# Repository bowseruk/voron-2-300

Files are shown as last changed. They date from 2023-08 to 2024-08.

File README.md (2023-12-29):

# Voron 2.4 300mm

)

## Description

This Repo is for keeping all the details of my Voron 2.4r2 300 mm.

The project had the following aims:

- It has a place to store all STLs used to make the printer.

- Relevant documentation used in the build is stored.

- Store the relevant configuration files that have been modified and used in this build.

- Add some scripts to help maintain the printer.

## Table of Contents

- [Description](#description)

- [Table of Contents](#table-of-contents)

- [Installation](#installation)

- [Usage](#usage)

- [Features](#features)

- [Parts](#parts)

- [Credits](#credits)

- [License](#license)

## Installation

The project does not require installation steps.

## Usage

This is a record of everything in use on my printer. Feel free to use anything on this Repo when building your printer.

## Features

This project has the following features:

- Script to update canbus firmware.

- Saved configuration files based on research and experimentation to date.

## Parts

The printer was built with:

- A Formbot 2.4r2 kit with Dragon HF, Octopus Pro and Raspberry Pi 3.

It has been modified with the following upgrades:

- 2020 extrusion covers to neaten led, camera and thermistor wiring.

- ACM Deck and Back Panels

- BTT Smart Sensor v2

- BTT Relay v1.2 and mount

- BTT UPS 24v and mount

- Chaotic Labs CNC Kit (Part of it) (Z and X/Y Idlers and A/B motor mount)

- Corner Cable Cover

- Daylight on a Stick (x2) and mount

- Disco on a Stick and mount

- Extrusion Backers

- Fysetc PITB

- G5EC Z Joints

- IGUS Z chain (Formbot supplied one was too thick and interfered with the y endstop)

- Kinematic Bed + Bed Wagos

- LDO rails on Y (after a rail lost it bearings)

- Logitech C930C and mount

- Mellow Fly-SB2040

- Nevermore Micro V5

- Pi Camera and mount

- POWGE Z Gears (Formbot supplied one had a strip grub on gear, so damaged it getting it off)

- Raspberry Pi Mount

- Stealthburner

- Thermistors and mounts on gantry and top of enclosure

- WAGO mounts

- Wiring (large amount replaced or customised)

- Z Belt clips

## Credits

The following resources were important for this project.

- [Readme Generator](https://github.com/bowseruk/readme-generator-nodejs) for generating the readme.

- [Voron Design](https://vorondesign.com/voron2.4) for creating a great printer.

- [Klipper](https://www.klipper3d.org/) documentation has helped me a lot.

- [Katapult]()

- [Fluidd]()

- [Formbot](https://www.formbot3d.com/collections/voron-24)

- [2020 extrusion clips]()

- [BTT Octopus Pro](https://github.com/bigtreetech/BIGTREETECH-OCTOPUS-Pro) documentation for the Octopus Pro Board.

- [BTT Smart Filament Mount](https://mods.vorondesign.com/detail/yrBU4iTiddQRSvLqSDWMuA) by Empusas

- [BTT Relay v1.2 mount]()

- [BTT UPS 24v Mount](https://mods.vorondesign.com/detail/fyvvcExQHVCdg67SgMWcQ) by Oakman

- [Chaotic Labs CNC Kit](https://chaoticlab.xyz/) (Part of it) (Z and X/Y Idlers and A/B motor mount)

- [Corner Cable Cover](https://mods.vorondesign.com/detail/rXJYi9H1vNzno2fZlwAB3g)

- [Daylight on a Stick](https://github.com/VoronDesign/Voron-Hardware/tree/master/Daylight) and [mount]()

- [Disco on a Stick](https://github.com/VoronDesign/Voron-Hardware/tree/master/Daylight/Disco_on_a_stick) and [mount]()

- [Extrusion Backers](https://mods.vorondesign.com/detail/ewDI1Cntz7urtuq3Cm9wGQ)

- [Fysetc PITB](https://github.com/FYSETC/FYSETC-PITB)

- [G5EC Z Joints](https://mods.vorondesign.com/detail/eB5T2RNQcYI4o6cilhpXEg) by hartk1213.

- [Kinematic Bed + Bed Wagos](https://github.com/tanaes/whopping_Voron_mods/tree/main/kinematic_bed)

- [Logitech C930C mount](https://mods.vorondesign.com/detail/HScp6sF2ld2ncp8XV99RDA)

- [Mellow SB2040](https://mellow-3d.github.io/fly_sb2040_v1_general.html) documentation for the Mellow Fly-SB2040.

- [Nevermore](https://github.com/nevermore3d/Nevermore_Micro)

- [Pi Camera mount](https://github.com/VoronDesign/VoronUsers/tree/master/printer_mods/richardjm/picam-corner)

- [Raspberry Pi Mount](https://mods.vorondesign.com/detail/cd8PlaXqhTQsgKSmgcPHw)

- [Stealthburner](https://vorondesign.com/voron_stealthburner)

- [Thermistor mounts on gantry](https://mods.vorondesign.com/detail/x6rfcH51foFjGStyvPXnw)

- [Thermistor mounts on top of enclosure](https://mods.vorondesign.com/detail/dfRX88k7wwS6tpYlvyCEw)

- [WAGO mounts](https://mods.vorondesign.com/detail/u6PTkFoOllSE4jmasKCHQ)

- [Z Belt clips](https://mods.vorondesign.com/detail/UrXS8J4mIe1K3XGGagS5Q)

## License

)

This project is licensed under the [GNU GPL v3](https://opensource.org/license/gpl-3-0/) license.

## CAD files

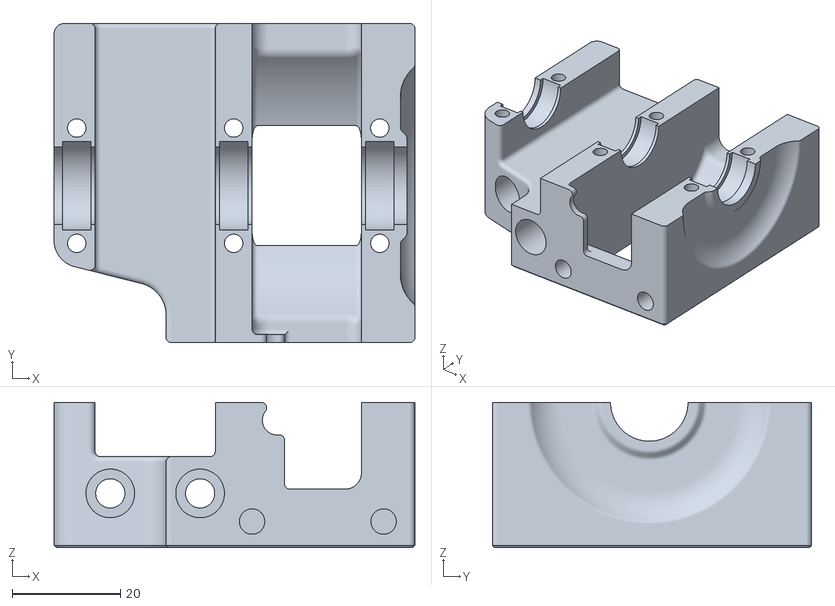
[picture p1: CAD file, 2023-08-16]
stl/Z Drive/z_drive_main_b_x2.stl
66.7 x 59.0 x 26.8

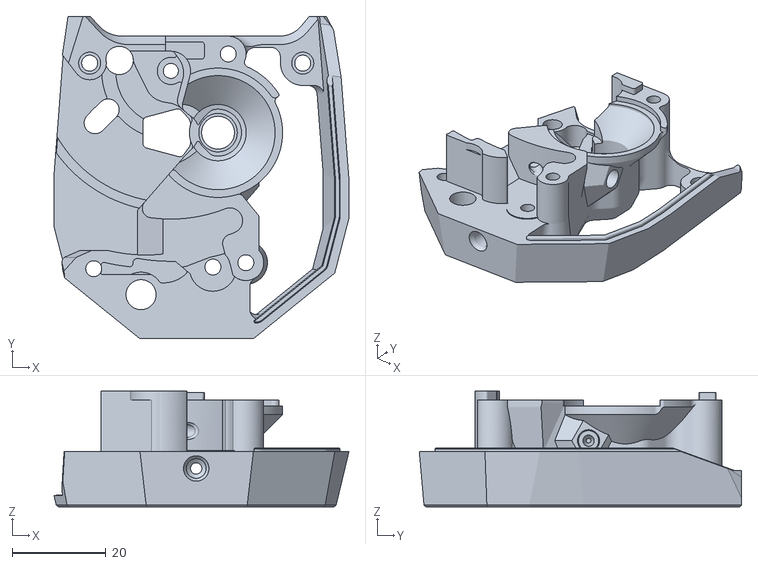
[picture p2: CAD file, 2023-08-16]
stl/Tools/main_body.stl
62.8 x 68.7 x 24.7

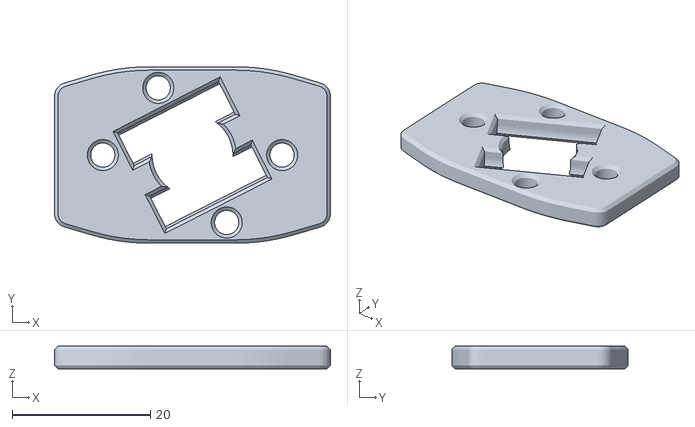
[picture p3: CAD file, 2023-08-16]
stl/Bed/[a]_sandwich_spacers-front_right.stl
40.0 x 25.5 x 3.30

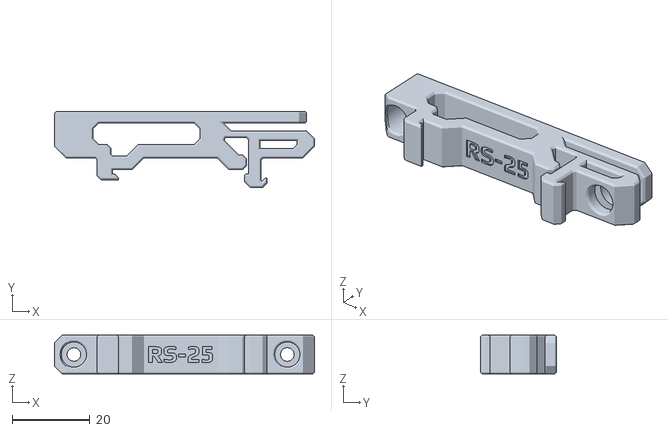
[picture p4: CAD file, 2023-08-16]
stl/Electronics Bay/rs25_psu_bracket.stl
67.0 x 19.6 x 10.0

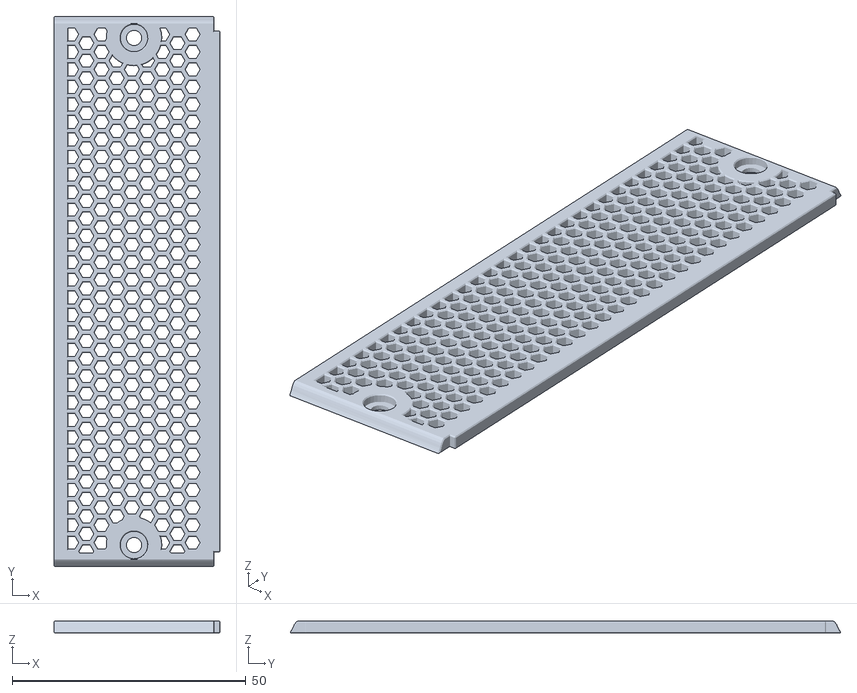
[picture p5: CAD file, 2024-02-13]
stl/Exhaust FIlter/1_lid.stl
35.5 x 117.8 x 2.55

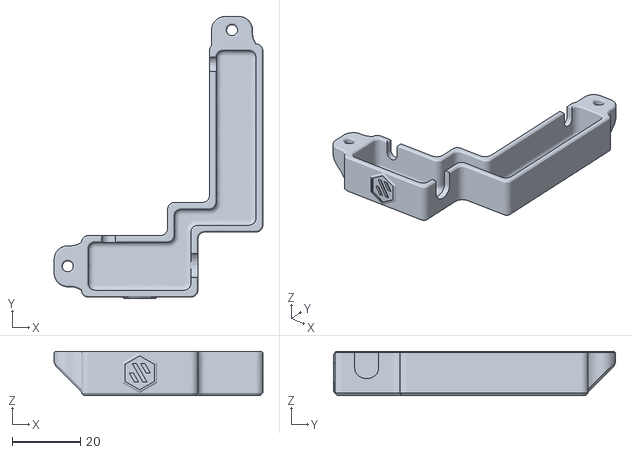
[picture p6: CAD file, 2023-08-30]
stl/Frame/[a]_top_corner_right_hide.stl
61.0 x 82.4 x 13.0

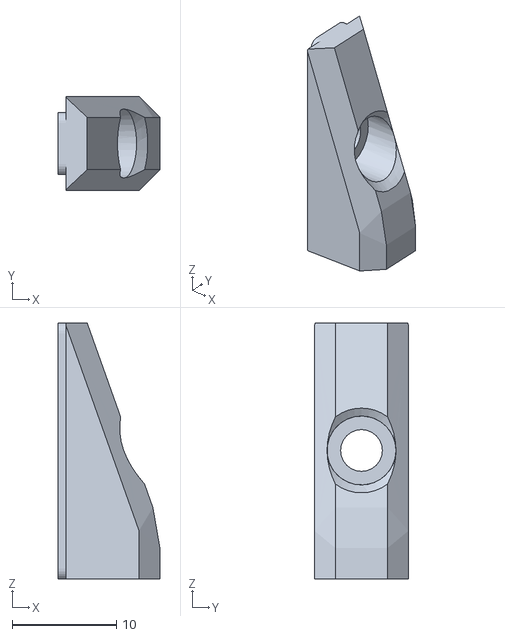
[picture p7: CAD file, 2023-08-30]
stl/Gantry/2020 Rail Endstop.stl
9.75 x 9.00 x 24.5

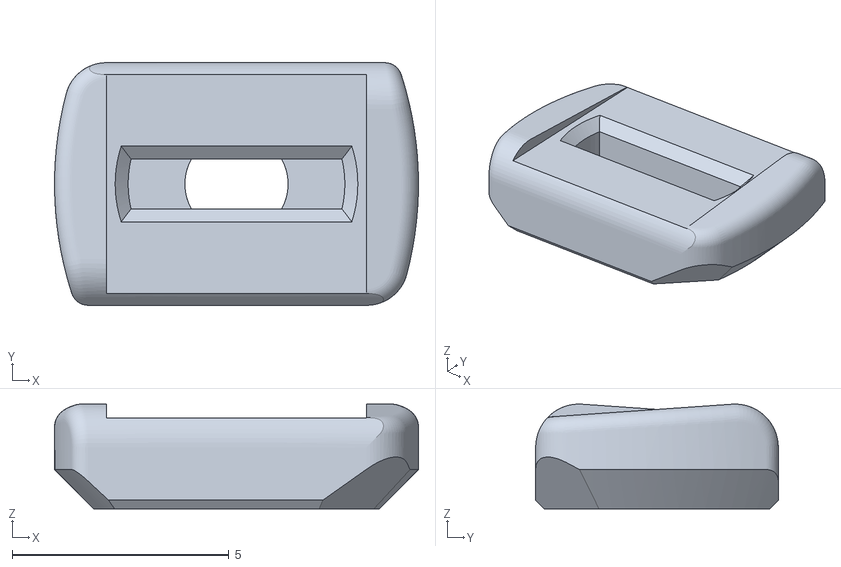
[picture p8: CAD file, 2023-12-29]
stl/Panel Mount/Unhammer-v2-Flat-Head.stl
8.40 x 5.60 x 2.42

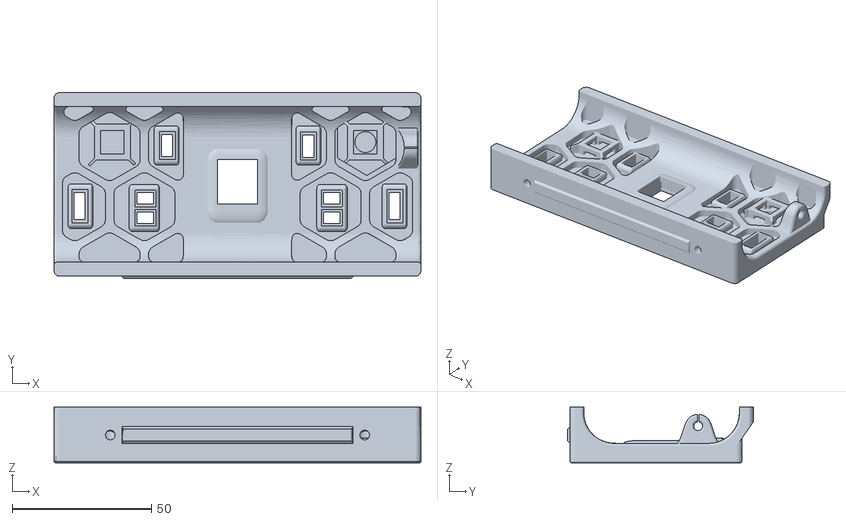
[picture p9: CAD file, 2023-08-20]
stl/Skirts/rear_center_skirt_300_custom.stl
132.0 x 66.8 x 20.0

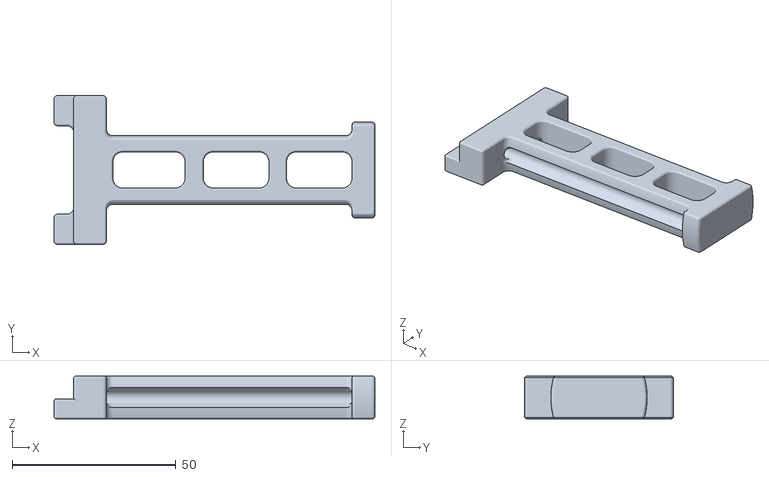
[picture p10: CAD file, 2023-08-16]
stl/Spool Management/spool_holder.stl
98.0 x 45.4 x 13.0

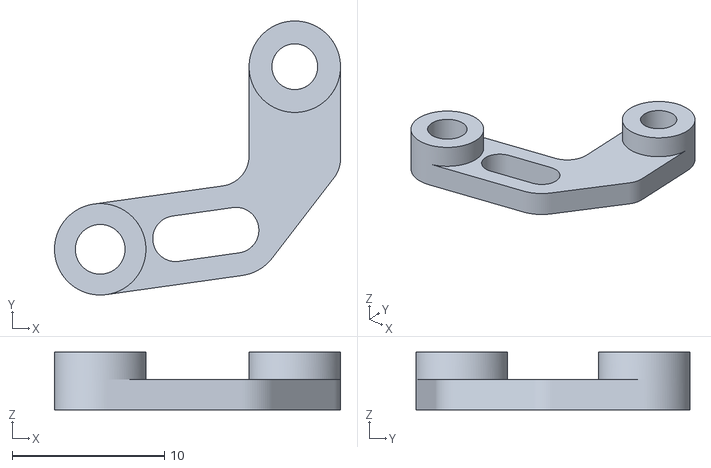
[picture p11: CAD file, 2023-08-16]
stl/Stealthburner/[a]_pcb_spacer.stl
18.8 x 18.0 x 3.80

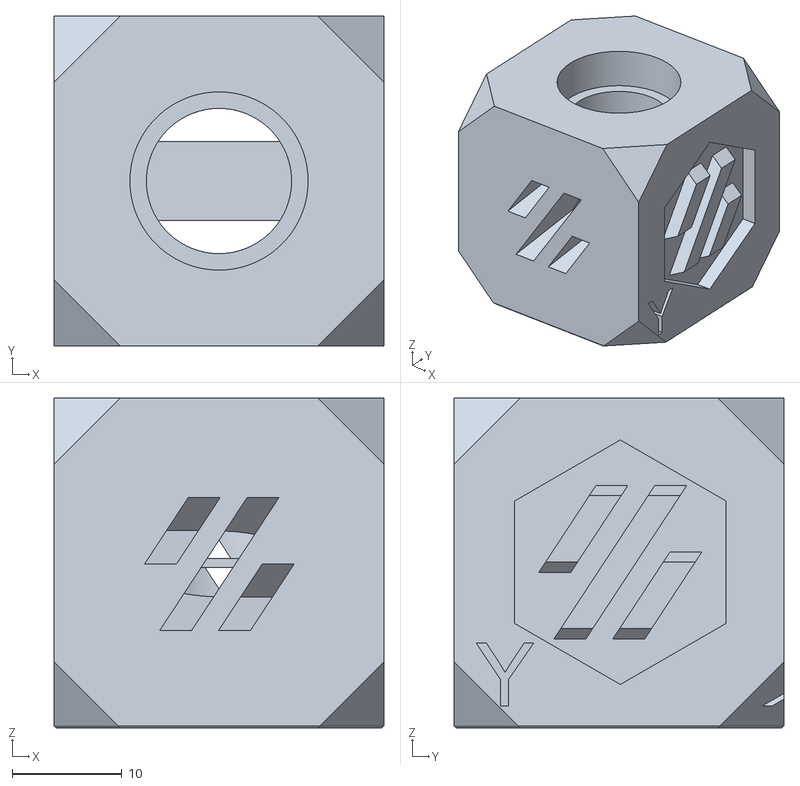
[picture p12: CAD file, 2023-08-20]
stl/Tools/Voron_Design_Cube_v7.stl
30.0 x 30.0 x 30.0

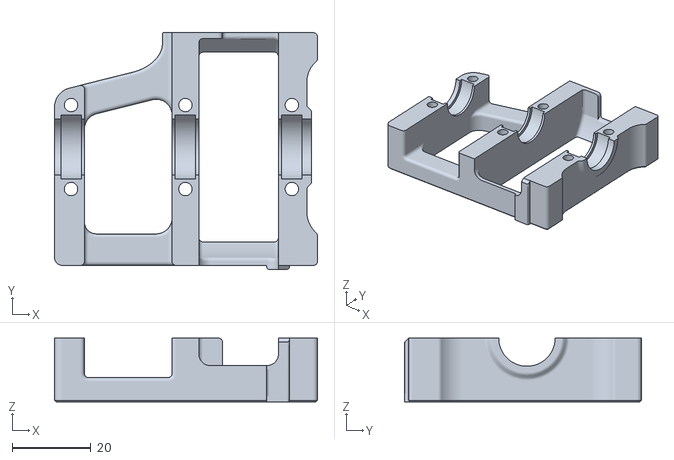
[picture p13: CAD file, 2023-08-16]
stl/Z Drive/z_drive_retainer_b_x2.stl
66.7 x 60.0 x 16.2

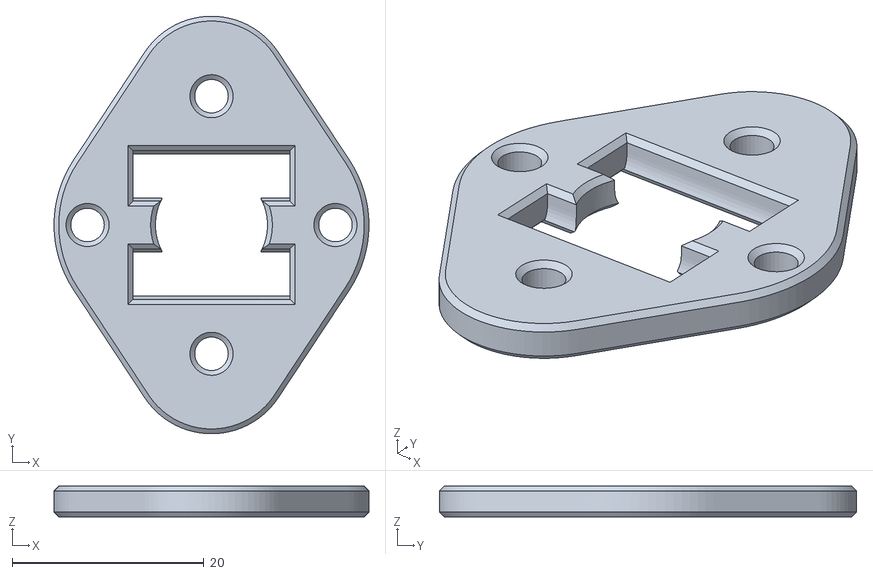
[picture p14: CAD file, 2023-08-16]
stl/Bed/[a]_sandwich_spacers-back_center.stl
32.9 x 43.6 x 3.20

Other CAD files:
stl/Z Drive/z_drive_main_a_x2.stl
stl/Electronics Bay/Wago_3x_221-415_DIN_Mount.stl
stl/Exhaust FIlter/exhaust_filter_housing(r2)Filament-Sensor.stl
stl/Frame/[a]_top_corner_left_hide.stl
stl/Bed/Bed_Support_Alignment_Tool_300_Corners_x4.stl
stl/Bed/Bed_Support_Alignment_Tool_Center_250_300_350_x2.stl
stl/Bed/Bed_WAGO.stl
stl/Bed/V2_Duo_Plenum.stl
stl/Bed/V2_Duo_Plenum_LID.stl
stl/Bed/[a]_sandwich_spacers-front_left.stl
stl/Electronics Bay/BTT_UPS_24V_DIN.stl
stl/Electronics Bay/Din_Mount_Bracket.stl
stl/Electronics Bay/Octopus_bracket_set.stl
stl/Electronics Bay/PSU_stabilizer_50mm.stl
stl/Electronics Bay/RPI_Metal_DIN_Mount.stl
stl/Electronics Bay/Wago_3x_221-415_Skirt_Inlet_Mount.stl
stl/Electronics Bay/lrs_200_psu_bracket_x2.stl
stl/Electronics Bay/pcb_din_clip_x3.stl
stl/Electronics Bay/wago_221-415_mount_3by5.stl
stl/Exhaust FIlter/1_coal_with_mesh.stl
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

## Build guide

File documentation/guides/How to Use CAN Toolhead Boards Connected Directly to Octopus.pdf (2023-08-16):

How to Use CAN Toolhead Boards Connected Directly to Octopus / Octopus Pro on CanBoot

- Klipper has a new CAN bus feature, the USB to CAN bus bridge communication for Octopus boards (and other compatible MCUs).
- This feature allows the Octopus boards (and other compatible MCUs) to act as a USB to CAN bus adapter. This replaces the need for an adapter like a Raspberry Pi CAN HAT, canable adapter, or the Bigtreetech U2C board.

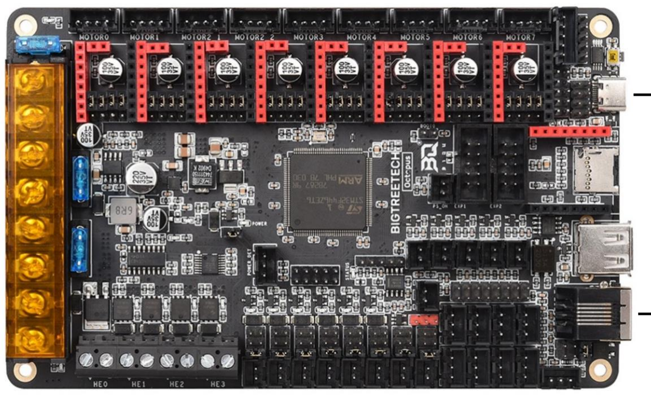
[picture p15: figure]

What is CanBoot?

- CanBoot is a custom bootloader loaded onto your Octopus and EBB board that allows users to update Klipper firmware over USB, UART, or CAN comms without physically having to access the board reset buttons or BOOT jumpers.
- It uses the same ‘make menuconfig’ setup to configure and compile firmware.
- CanBoot is NOT required to use the Klipper USB to CAN bus bridge comms. But I have not tested this comms feature separately.

You Will Need the Following

- USB-A to USB-C cable
- Power supply for Octopus and EBB toolboard (i.e. printer)
- RJ11 or RJ12 telephone cable, crimped to connect EBB board to Octopus
- See wiring info at end of guide. Best to setup wiring before installing software.
- Raspberry Pi, or similar, with Klipper / Moonraker / UI installed and working
- Computer with following software:
- SSH terminal software, I use PuTTY or Windows CMD
- WinSCP, to transfer files between Raspberry Pi and computer
- I also use Windows CMD to do this
- STM32CubeProgrammer
- Download for your computer OS and install
- https://www.st.com/en/development-tools/stm32cubeprog.html#get-software (https://www.st.com/en/development-tools/stm32cubeprog.html%23get-software)

High Level Instructions, for Understanding

1. Install CanBoot on Raspberry Pi, flash firmware to boards
a. Configure and compile CanBoot firmware for Octopus / Pro and EBB
b. Flash CanBoot to boards using STM32CubeProgrammer and computer
2. Setup boards for Klipper
a. Octopus - Setup Klipper for USB to CAN bus bridge, with CAN comms to EBB
b. EBB - Setup Klipper for CAN comms
c. Find serial device for Octopus / Pro on Raspberry Pi
d. Flash Klipper to Octopus / Pro with CanBoot serial command
3. Setup can0 network on Raspberry Pi, power cycle printer
4. Find CAN uuid for Boards
a. Connect EBB to Octopus / Pro, power cycle printer
5. Flash Klipper to EBB board with CanBoot CAN command
6. Printer Config Update and General Tips
7. How to Use CanBoot to update boards, Tips

Okay, enough talking! Let’s get started!

Instructions________________________________________________________________________

1. Install CanBoot on Raspberry Pi, flash firmware to boards

Start your SSH terminal.

sudo apt-get install git -y #Do this if you haven’t installed git yet…

git clone https://github.com/Arksine/CanBoot

cd CanBoot

make menuconfig

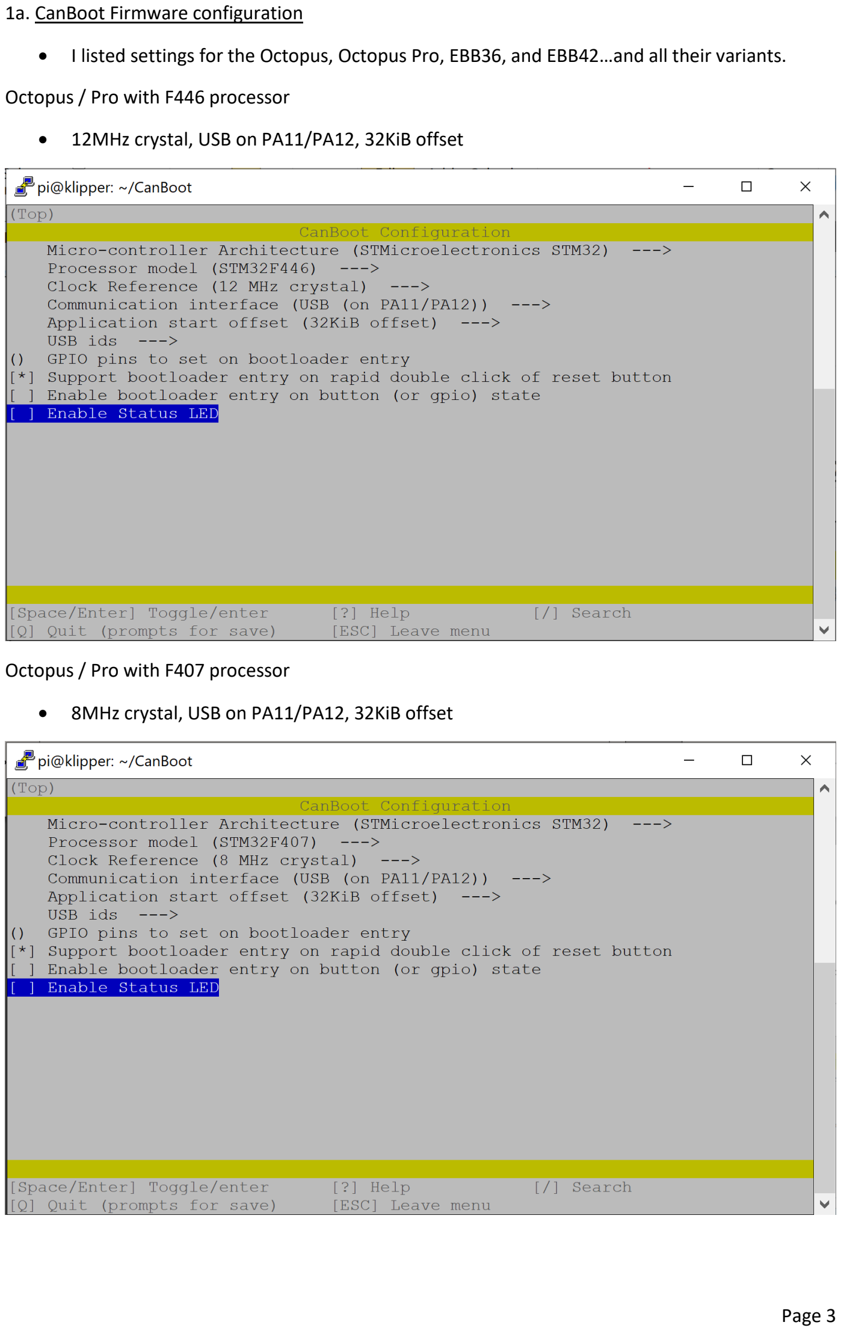
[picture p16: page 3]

1a. CanBoot Firmware configuration

- I listed settings for the Octopus, Octopus Pro, EBB36, and EBB42…and all their variants.

Octopus / Pro with F446 processor

- 12MHz crystal, USB on PA11/PA12, 32KiB offset

Octopus / Pro with F407 processor

- 8MHz crystal, USB on PA11/PA12, 32KiB offset

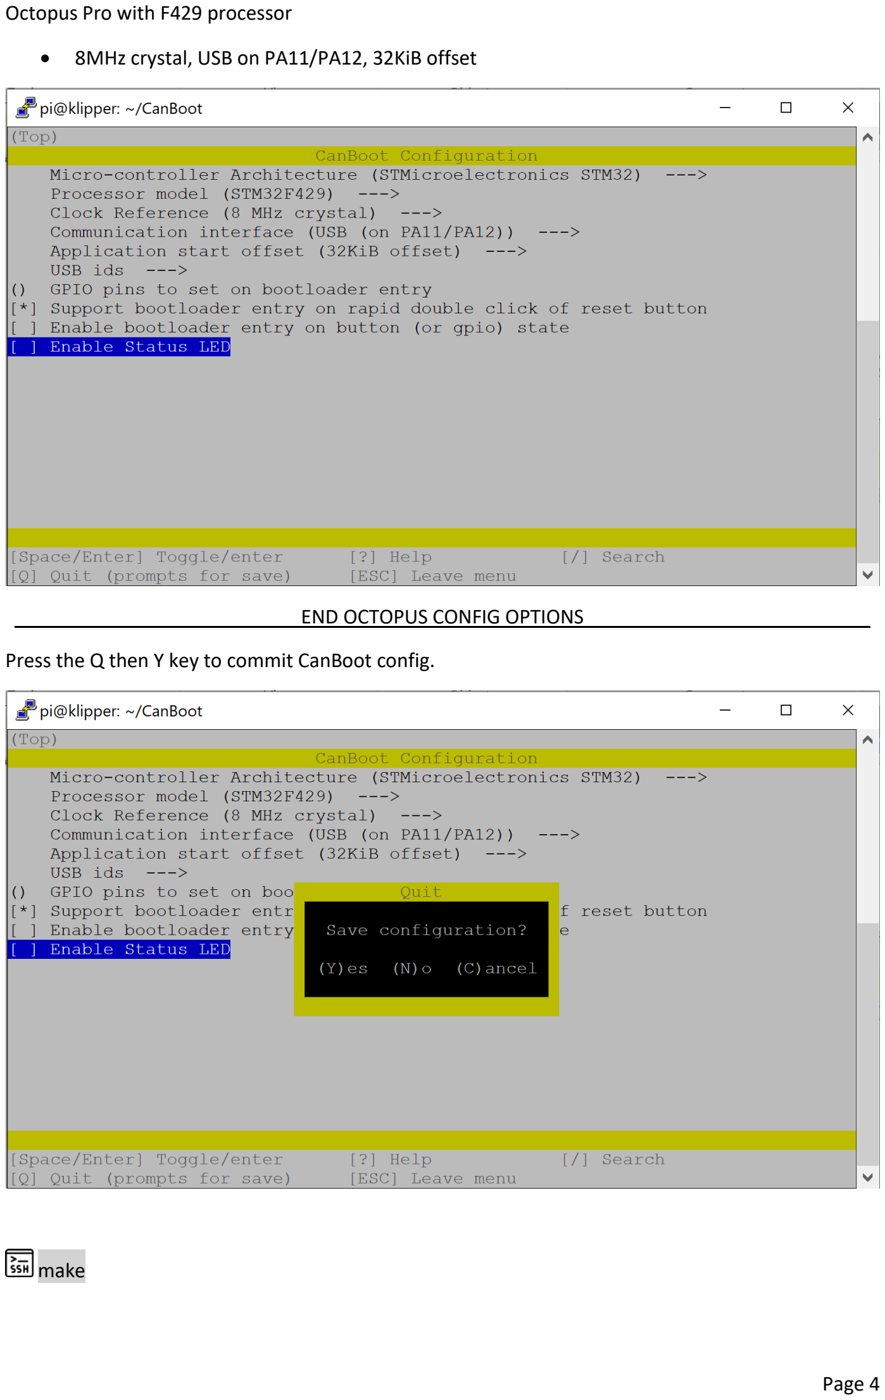
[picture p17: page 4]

Octopus Pro with F429 processor

- 8MHz crystal, USB on PA11/PA12, 32KiB offset

___________________________END OCTOPUS CONFIG OPTIONS___________________________

Press the Q then Y key to commit CanBoot config.

make

You have now created a canboot.bin firmware file for your Octopus board. My approach is to now make the CanBoot firmware for the EBB board. But if you do this now it will override the Octopus firmware you just created. So do the following:

On your computer, open a Windows CMD terminal

Type: pscp -C pi@<IP_ADDRESS>:/home/pi/CanBoot/out/canboot.bin octopus_canboot.bin

- Make sure to replace <IP_ADDRESS> with your Pi IP address or network name, like fluiddpi.local

NOTE: You can also manually move the canboot.bin file to your computer with WinSCP. Make sure to name it octopus_canboot.bin (or similar). We will be moving an ebb_canboot.bin file next.

…Back to the Raspberry Pi SSH terminal

make clean

make menuconfig

EBB36 / EBB42 v1.0 with F072 processor

- 8MHz crystal, CAN bus on PB8/PB9, 8KiB offset, 500000 CAN bus speed

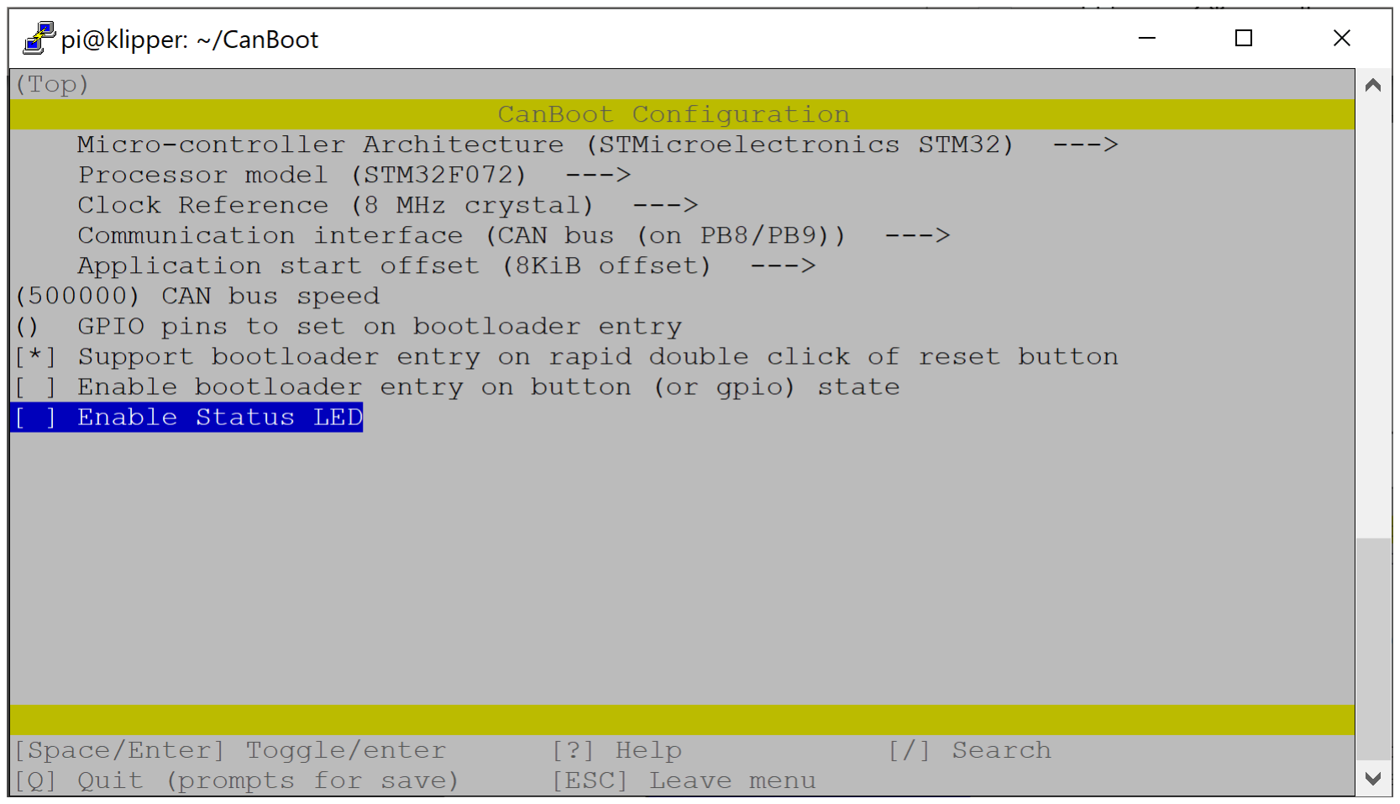
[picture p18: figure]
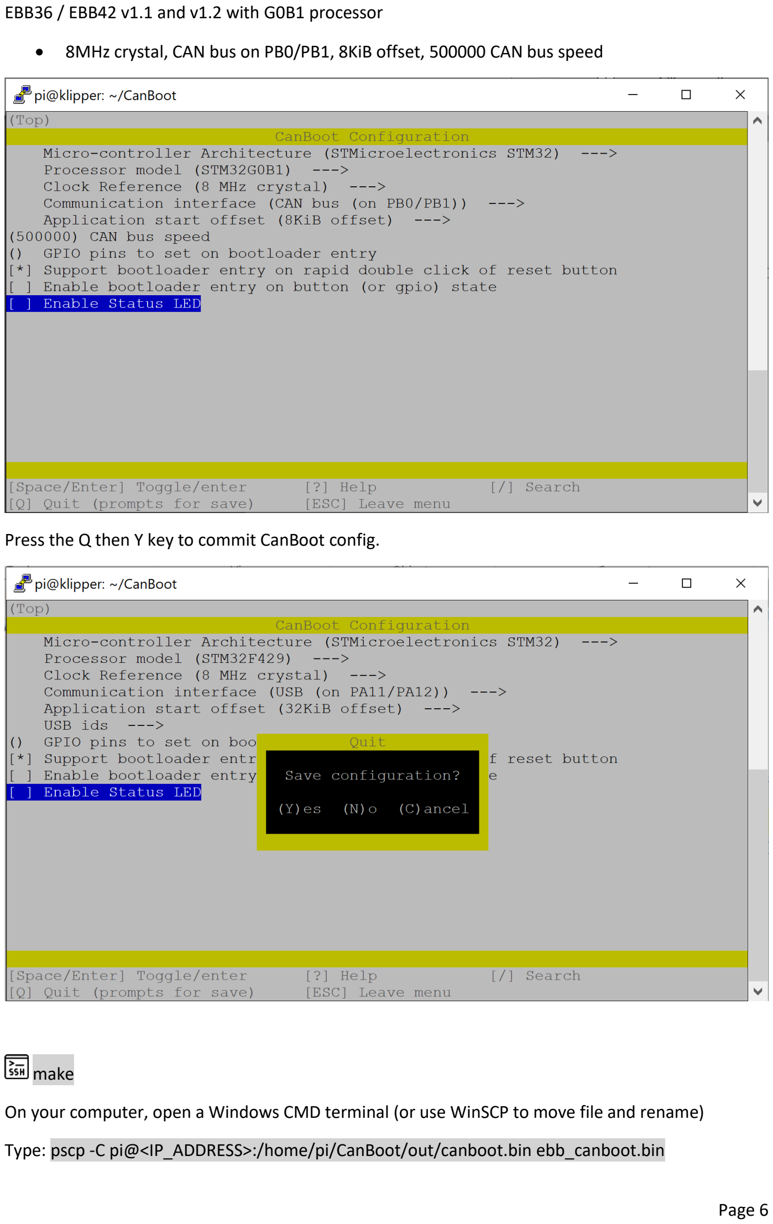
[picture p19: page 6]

EBB36 / EBB42 v1.1 and v1.2 with G0B1 processor

- 8MHz crystal, CAN bus on PB0/PB1, 8KiB offset, 500000 CAN bus speed

Press the Q then Y key to commit CanBoot config.

make

On your computer, open a Windows CMD terminal (or use WinSCP to move file and rename)

Type: pscp -C pi@<IP_ADDRESS>:/home/pi/CanBoot/out/canboot.bin ebb_canboot.bin

- Make sure to replace <IP_ADDRESS> with your Pi IP address or network name, like fluiddpi.local

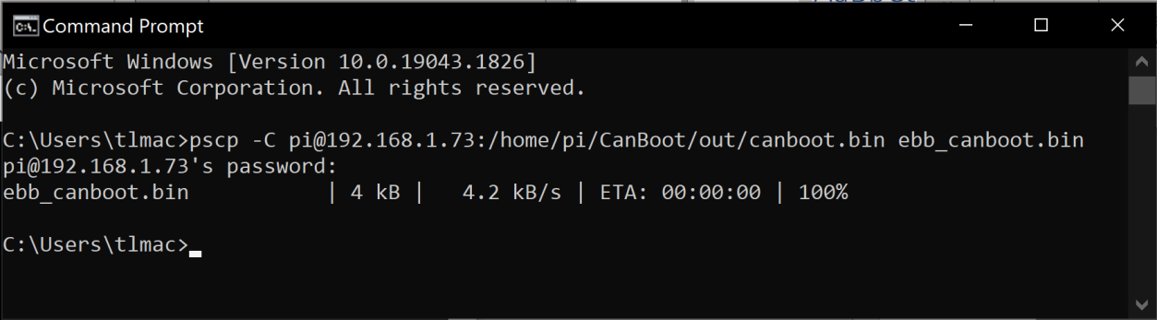
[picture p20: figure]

Your two CanBoot firmware files are now on your computer (in your user folder). Next step is to flash CanBoot to your boards.

1b. Flash CanBoot using STM32CubeProgrammer

You’ll need to put your boards into DFU mode and connect to the computer using a USB-A to USB-C cable. Boot instructions for the Octopus and Octopus Pro are below:

Make sure the power is off to the Octopus board

- To start have the USB-C to USB-A cable connected between the Windows PC and the Octopus Board.
- Remove the USB-C power jumper and place a jumper on the Boot0 header.

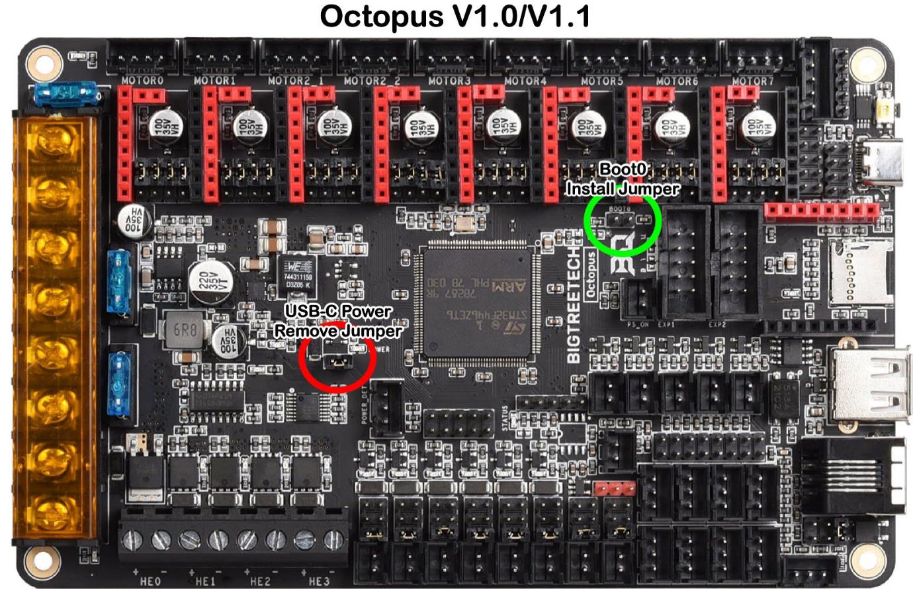
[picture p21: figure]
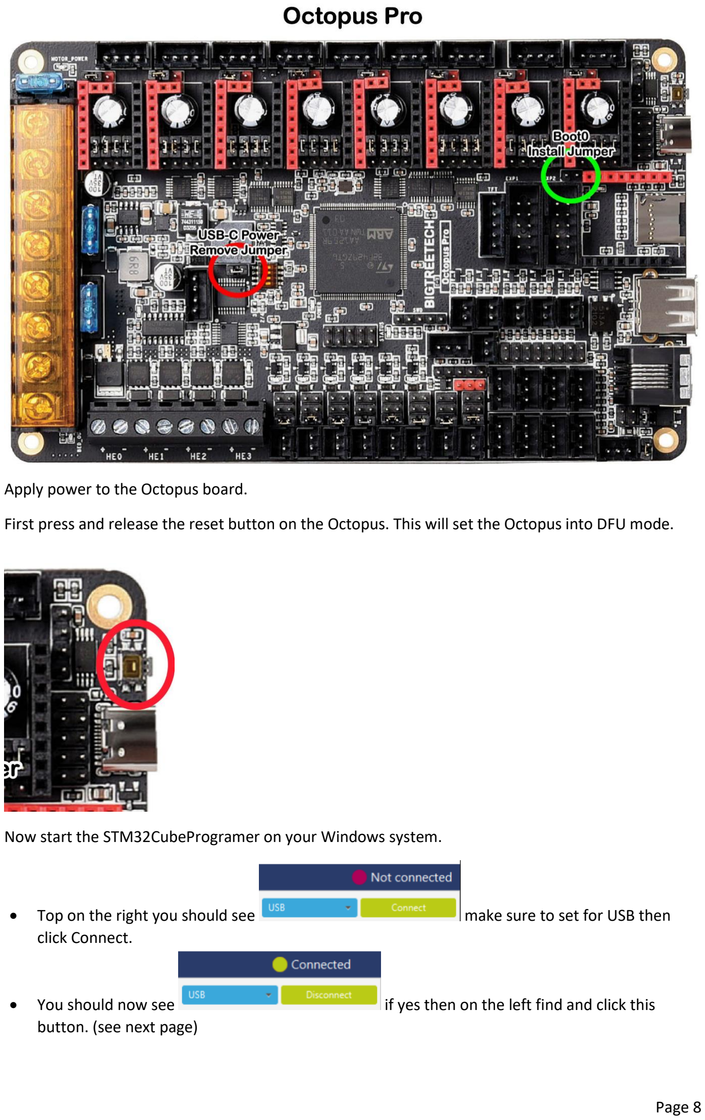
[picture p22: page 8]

Apply power to the Octopus board.

First press and release the reset button on the Octopus. This will set the Octopus into DFU mode.

Now start the STM32CubeProgramer on your Windows system.

- | Top on the right you should see | make sure to set for USB then
| click Connect.
- | You should now see | if yes then on the left find and click this
| button. (see next page)

- For CanBoot and Klipper to work correctly we need to wipe the flash memory by clicking this button.

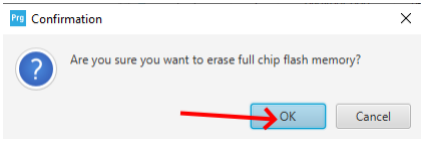
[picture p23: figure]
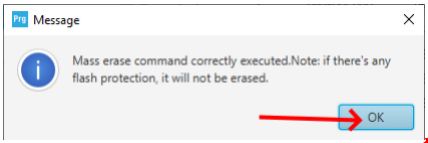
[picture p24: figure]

- Go back to main page by clicking on this button

- Select (1) “Open File” tab, find the octopus_canboot.bin file, and (2) download to your Octopus board. (3) Click Disconnect when done.

Power off your Octopus board. Remove the jumper from BOOT0.

Now you’ll flash your EBB toolboard.

This step will power the toolboard from USB only. Place a jumper on VBUS header.

EBB36 / EBB42 v1.0

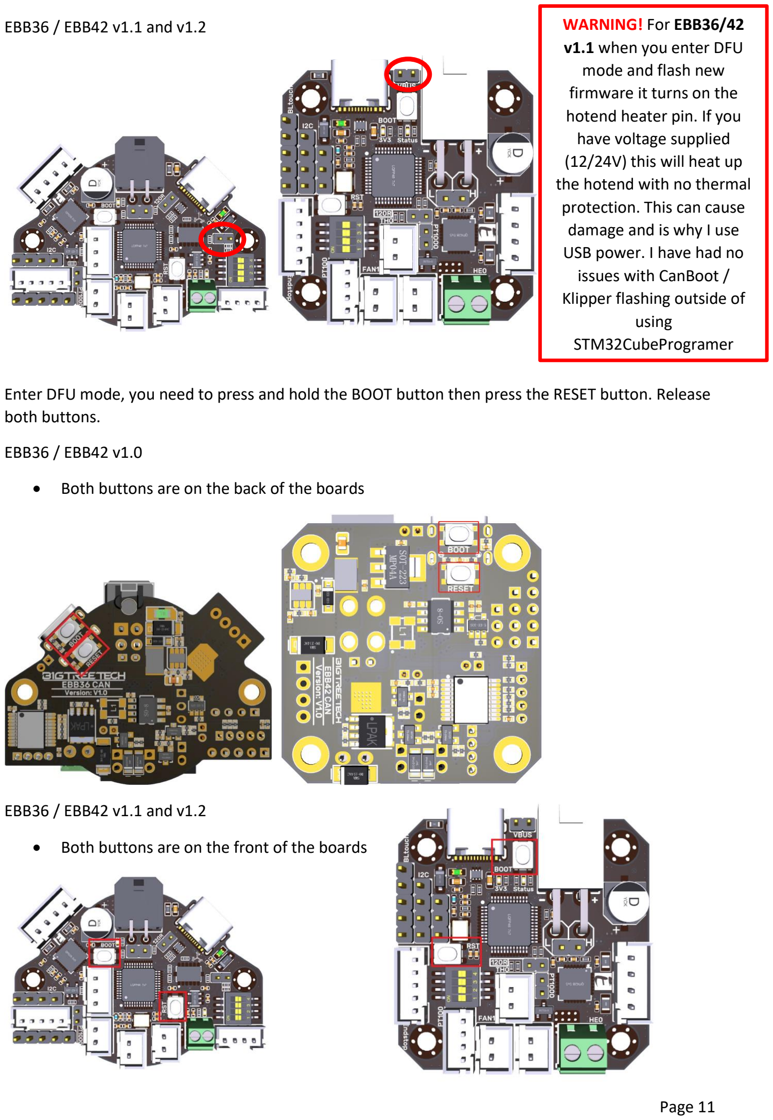
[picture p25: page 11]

EBB36 / EBB42 v1.1 and v1.2

Enter DFU mode, you need to press and hold the BOOT button then press the RESET button. Release both buttons.

EBB36 / EBB42 v1.0

- Both buttons are on the back of the boards

EBB36 / EBB42 v1.1 and v1.2

- Both buttons are on the front of the boards

WARNING! For EBB36/42
v1.1 when you enter DFU
mode and flash new
firmware it turns on the
hotend heater pin. If you
have voltage supplied
(12/24V) this will heat up the hotend with no thermal protection. This can cause damage and is why I use
USB power. I have had no
issues with CanBoot /
Klipper flashing outside of using
STM32CubeProgramer

Now start the STM32CubeProgramer on your Windows system.

- | Top on the right you should see | make sure to set for USB then
| click Connect.
- | You should now see | if yes then on the left find and click this
| button.
- For CanBoot and Klipper to work correctly we need to wipe the flash memory by clicking this button.

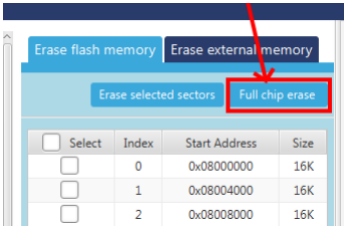
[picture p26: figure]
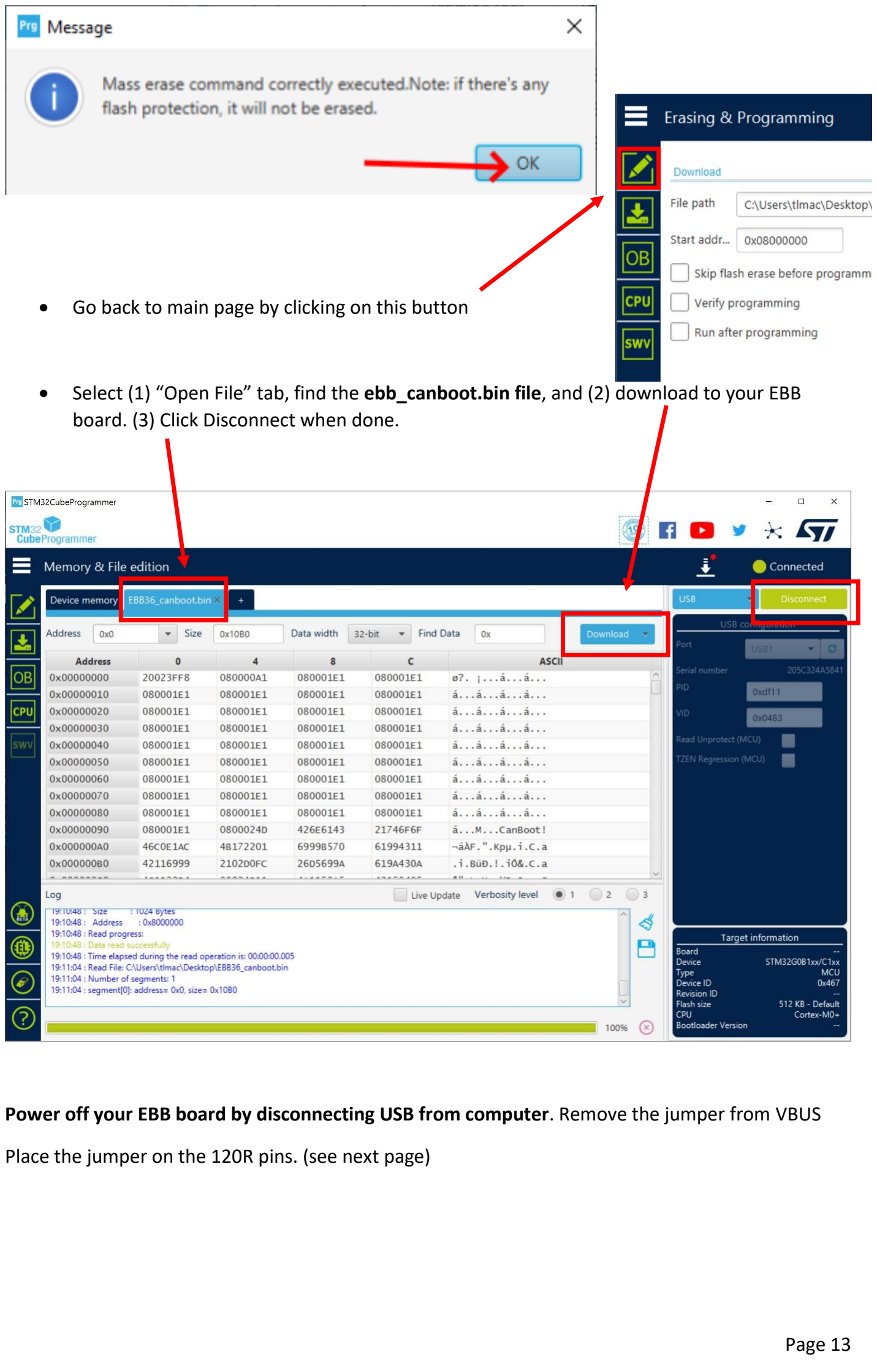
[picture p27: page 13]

- Go back to main page by clicking on this button
- Select (1) “Open File” tab, find the ebb_canboot.bin file, and (2) download to your EBB board. (3) Click Disconnect when done.

Power off your EBB board by disconnecting USB from computer. Remove the jumper from VBUS

Place the jumper on the 120R pins. (see next page)

EBB36 / EBB42 v1.0

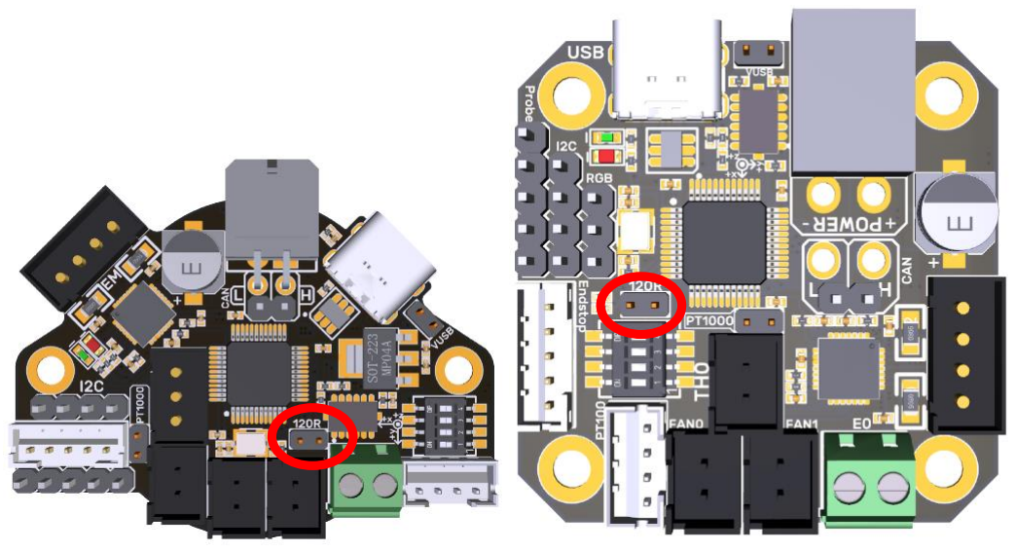
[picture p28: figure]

EBB36 / EBB42 v1.1 and v1.2

Set aside the EBB toolboard for now.

2. Setup Octopus / Pro for Klipper

Go back to your SSH terminal window.

cd ~/klipper

make menuconfig

2a. Octopus - Setup Klipper for USB to CAN bus bridge, with CAN comms to EBB

You will now setup the new USB to CAN bus bridge on your Octopus / Pro board. Below are the Klipper config options for each board. Make sure to have “Enable extra low-level configuration options” selected.

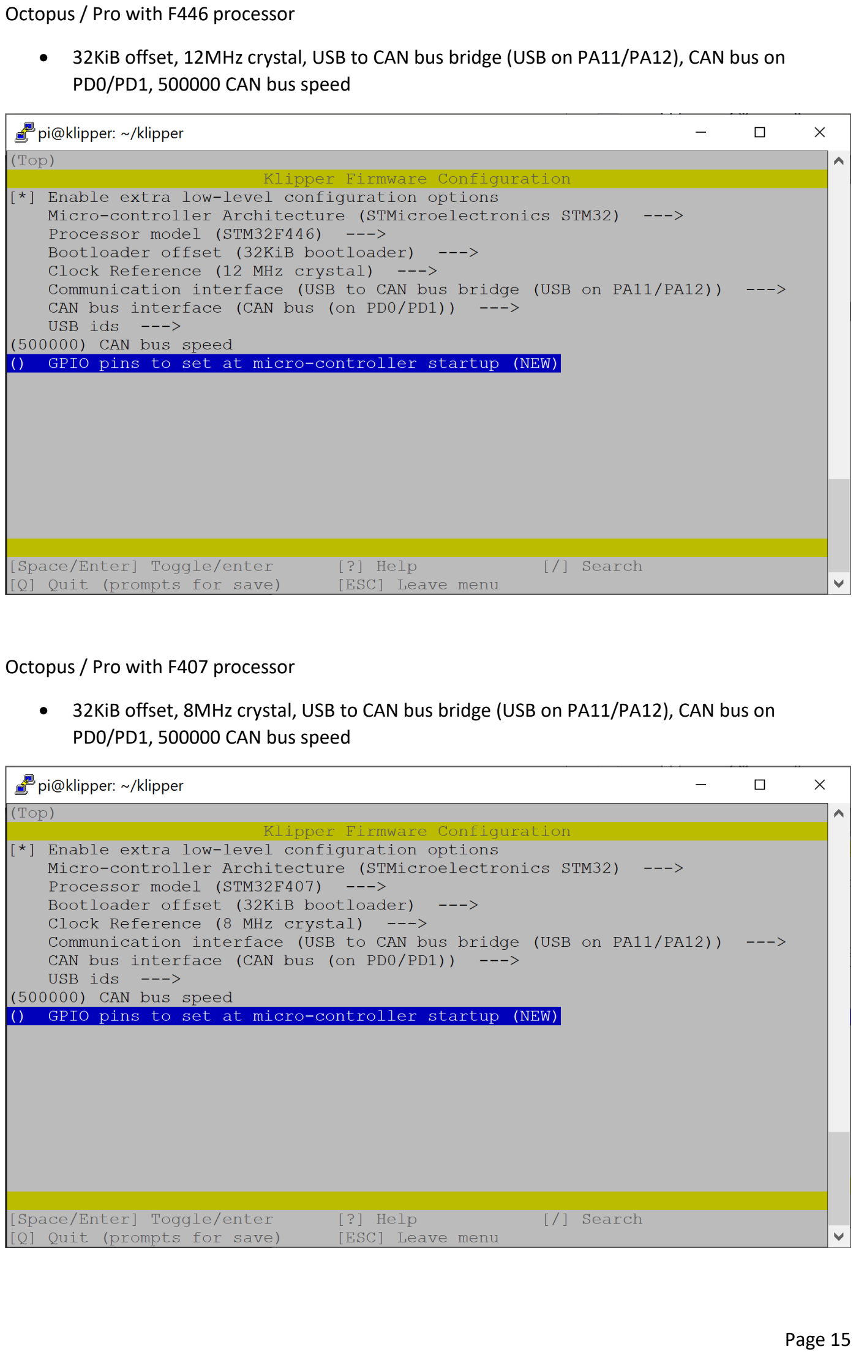
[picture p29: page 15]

Octopus / Pro with F446 processor

- 32KiB offset, 12MHz crystal, USB to CAN bus bridge (USB on PA11/PA12), CAN bus on PD0/PD1, 500000 CAN bus speed

Octopus / Pro with F407 processor

- 32KiB offset, 8MHz crystal, USB to CAN bus bridge (USB on PA11/PA12), CAN bus on PD0/PD1, 500000 CAN bus speed

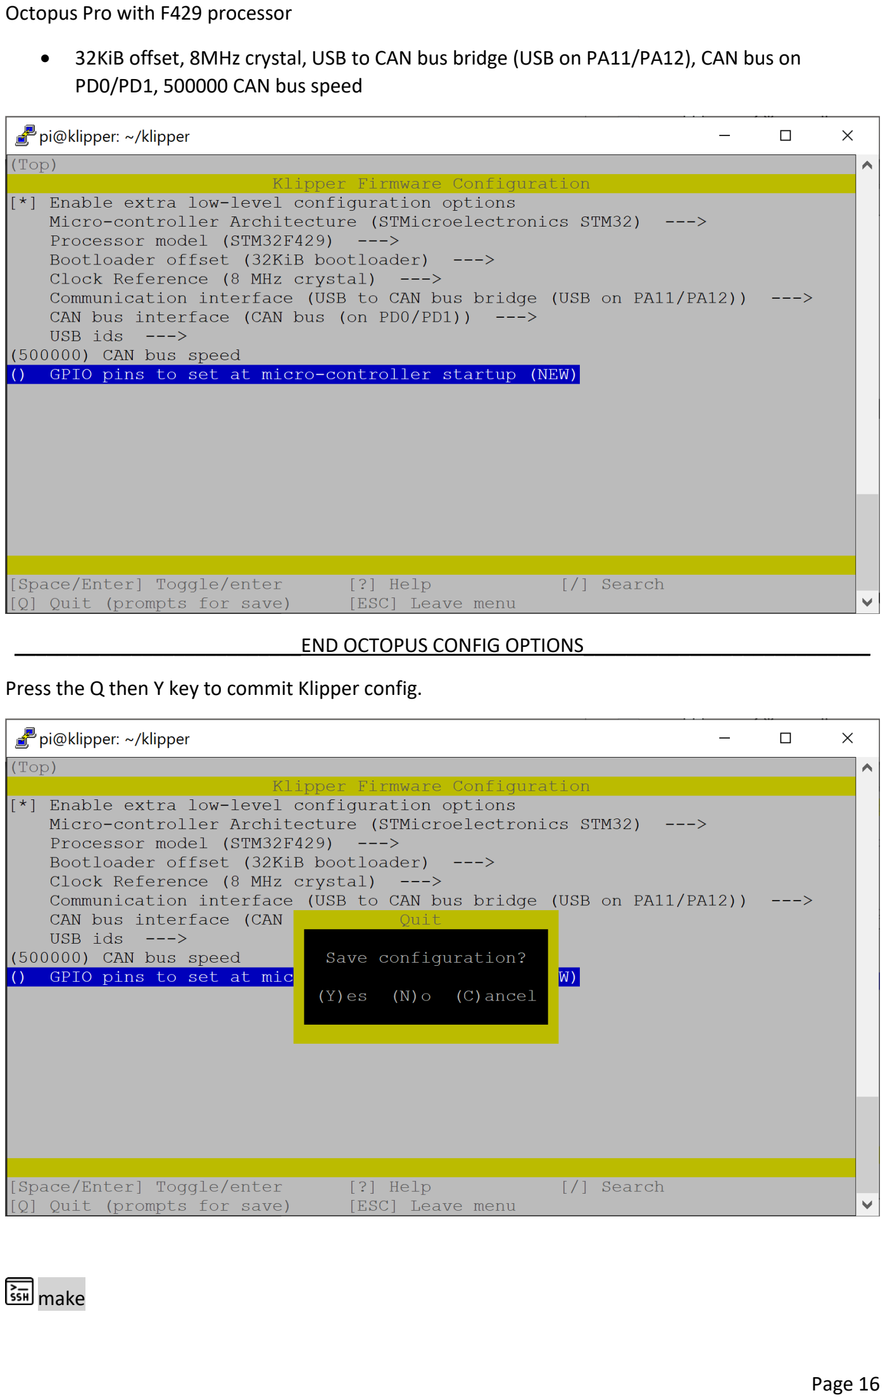
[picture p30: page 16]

Octopus Pro with F429 processor

- 32KiB offset, 8MHz crystal, USB to CAN bus bridge (USB on PA11/PA12), CAN bus on PD0/PD1, 500000 CAN bus speed

___________________________END OCTOPUS CONFIG OPTIONS___________________________

Press the Q then Y key to commit Klipper config.

make

NOTE:

Just like with the CanBoot firmware we will be making Klipper firmware for the Octopus / Pro board and the EBB board. Since we are already compiling Klipper firmware, I like to compile the EBB Klipper firmware now. But if we do, then the Octopus Klipper firmware we just made will be overwritten. So:

mv ~/klipper/out/klipper.bin octopus_klipper.bin

make clean

NOTE:

This moves the klipper firmware file to the klipper folder and renames it octopus_klipper.bin then deletes the compile files and folders, including /klipper/out

2b. EBB - Setup Klipper for CAN comms

make menuconfig

EBB36 / EBB42 v1.0 with F072 processor

- 8KiB bootloader, 8MHz crystal, CAN bus on PB8/PB9, 500000 CAN bus speed

EBB36 / EBB42 v1.1 / v1.2 with G0B1 processor

- 8KiB bootloader, 8MHz crystal, CAN bus on PB0/PB1, 500000 CAN bus speed

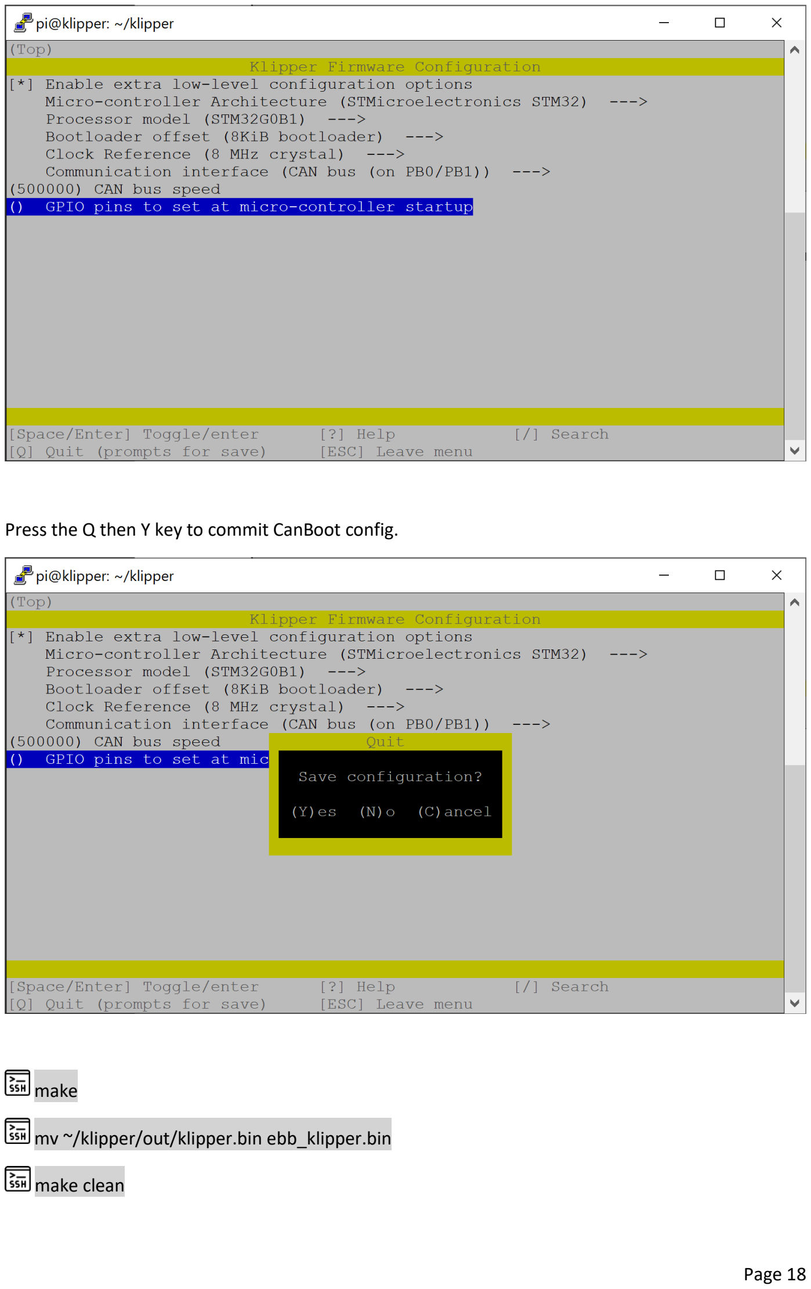
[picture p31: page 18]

Press the Q then Y key to commit CanBoot config.

make

mv ~/klipper/out/klipper.bin ebb_klipper.bin

make clean

2c. Find serial device for Octopus / Pro on Raspberry Pi

Connect your Octopus / Pro board to the Raspberry Pi with a USB-A to USB-C cable…connected to the USB-C port on the Octopus board. Power on your printer.

cd

ls /dev/serial/by-id/*

This will give you something similar to below. YOUR DEVICE WILL BE DIFFERENT!

Copy this, for example:

/dev/serial/by-id/usb-CanBoot_stm32f429xx_350026000B50314B33323220-if00

2d. Flash Klipper to Octopus / Pro with CanBoot serial command

cd CanBoot/scripts

pip3 install pyserial

…this only has to be done once

python3 flash_can.py -f ~/klipper/octopus_klipper.bin -d <serial_device>

NOTE: Replace <serial_device> with the path you copied earlier…

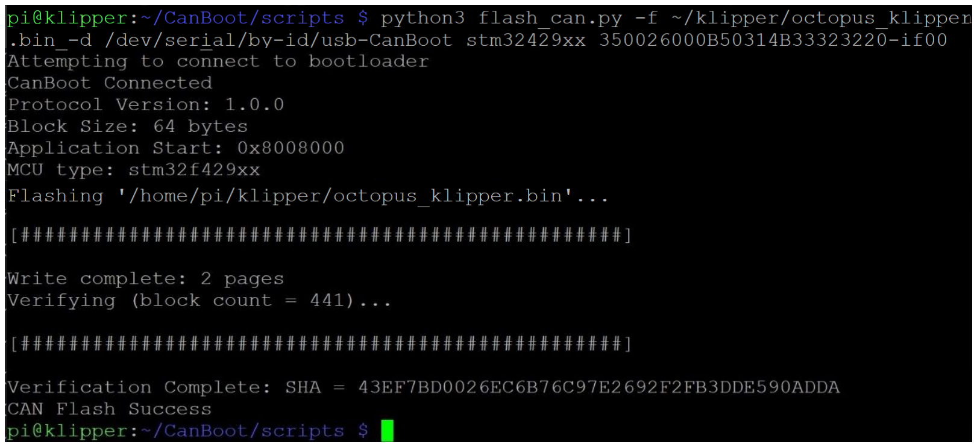
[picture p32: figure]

NOTE: The Octopus board communicates over USB initially. Only this flash (and Klipper updates, more on that later) use the serial device path. The Octopus board now has a CAN uuid…let’s find it!

3. Setup can0 Network on Raspberry Pi, Power Cycle Printer

Now we need to enable the can0 network and set it up so that we can have CAN bus working

cd

sudo nano /etc/network/interfaces.d/can0

- Copy and paste the following:

allow-hotplug can0
iface can0 can static
bitrate 500000
up ifconfig $IFACE txqueuelen 128

Ctrl – X to EXIT.

Key Y for YES, and ENTER.

Power off your printer. Time to plug in your EBB toolboard. Plug power and can data cables into EBB. Plug RJ11 or RJ12 connector into Octopus / Pro board.

Power on your printer.

NOTE:

We just created the can0 interface as a hot-plug network. This means that when something changes to devices, or new devices are connected, the network reacts. Power cycling the printer is a change that the can0 network detects and configures the Octopus to work as a CAN device. Also, this hot-plug option seems to make “firmware_restarts” smoother.

4. Find CAN uuid for Octopus / Pro

Now that can0 is setup, let’s make sure it is up and running.

ifconfig

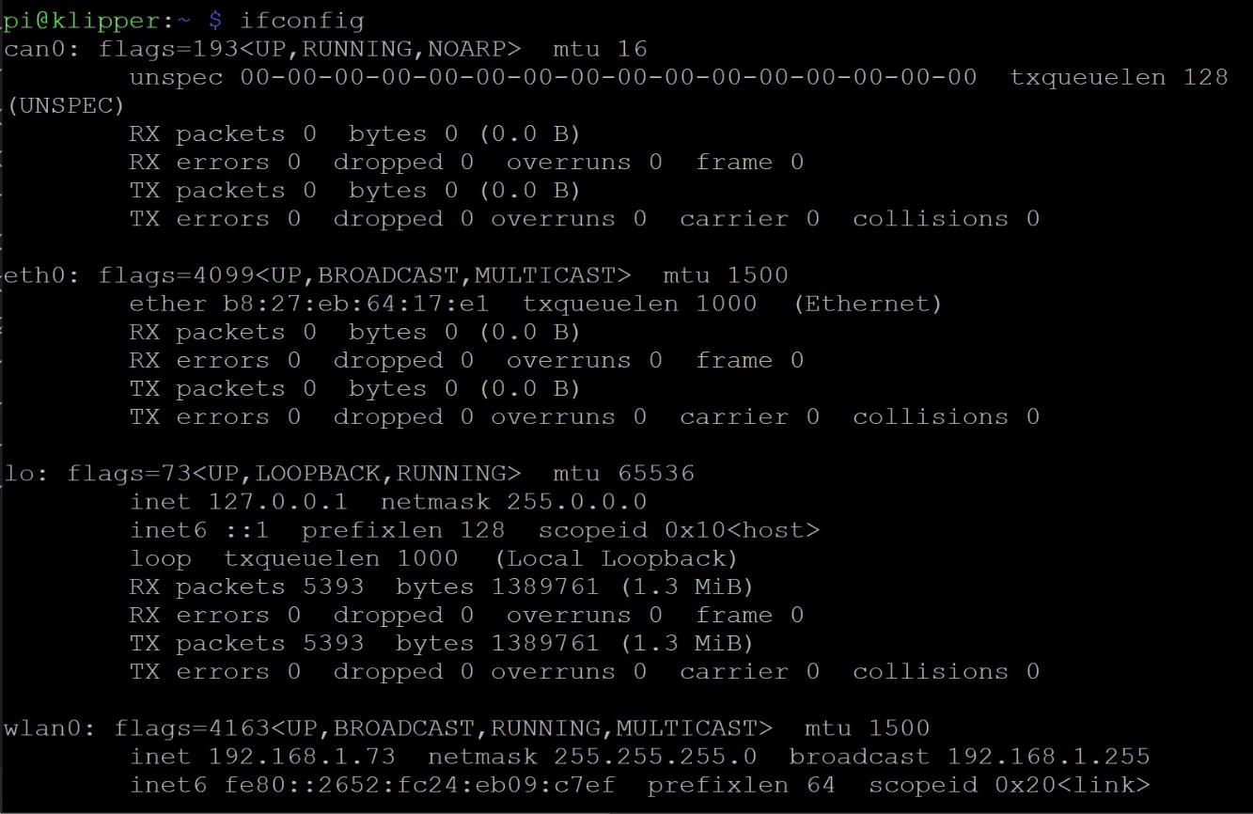
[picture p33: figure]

You should get results similar to this. We are looking for the can0 on top. Success!

NOTE: If this doesn’t work try to turn off power to your printer and reboot your Raspberry Pi. Wont booted back up, open a SSH terminal and try ifconfig again. Can0 won’t show up. Power on your printer and then try ifconfig. Should have can0 up and running.

cd CanBoot/scripts

python3 flash_can.py -i can0 -q

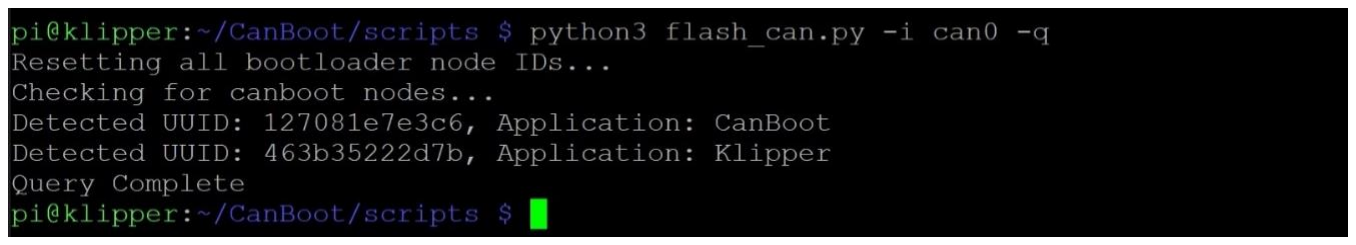
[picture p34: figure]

In this instance both EBB and Octopus are detected. The EBB only has CanBoot on it while the Octopus has Klipper. It is obvious which is which. Save both for later.

5. Flash Klipper to EBB board with CanBoot CAN command

python3 flash_can.py -f ~/klipper/ebb_klipper.bin -u <ebb_uuid>

NOTE: Replace <ebb_uuid> with the CAN uuid found before. The EBB is labelled with “CanBoot”. In this case mine is 127081e7e3c6

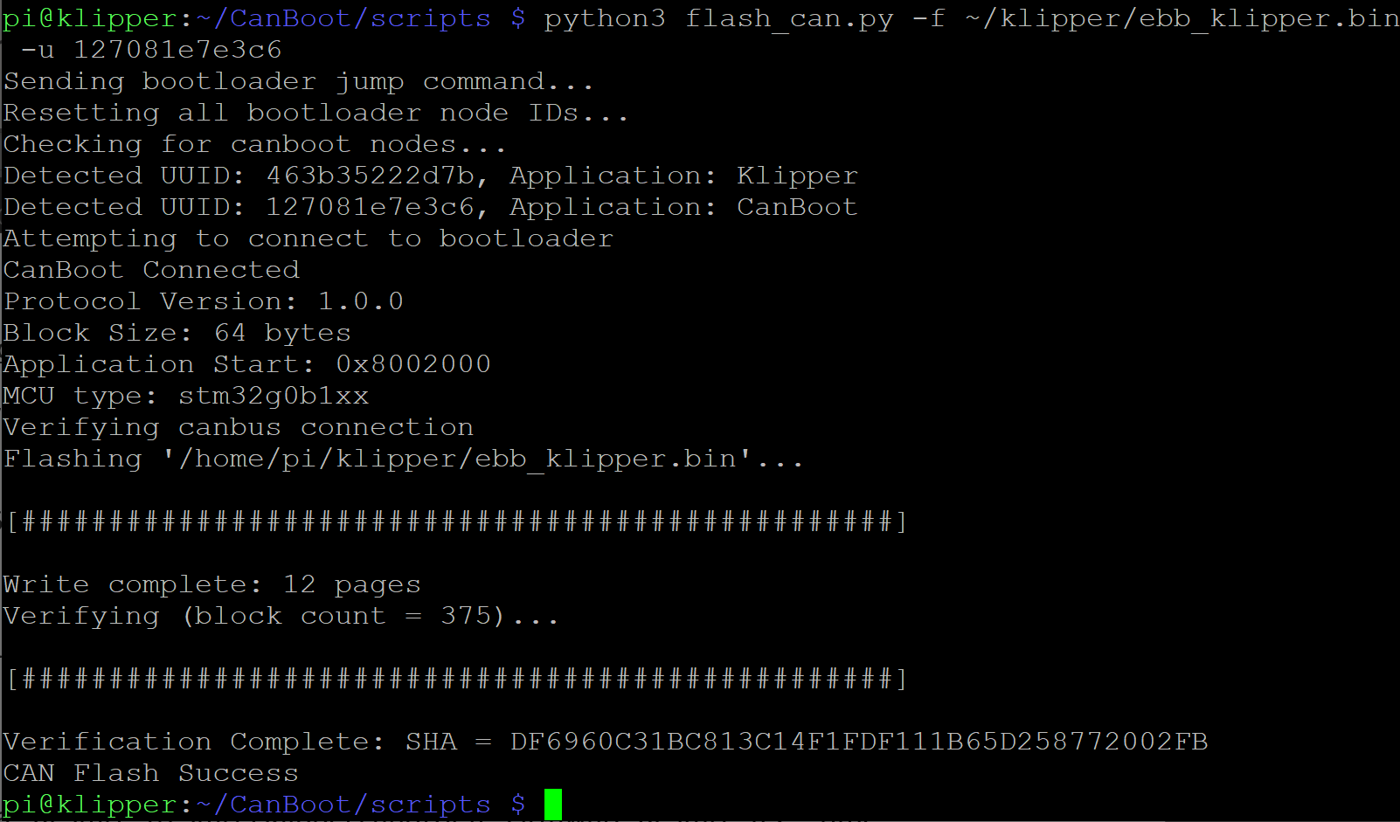
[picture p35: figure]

cd ~/klipper

rm octopus_klipper.bin ebb_klipper.bin

6. Printer Config Update and General Tips

Edit your printer.cfg to now include your new CAN uuid. For example:

[mcu]
canbus_uuid: 463b35222d7b

[mcu EBBCan]
canbus_uuid: 127081e7e3c6

Save and restart.

If you have issues here, try a “Restart” (restarts Klipper) and/or a “Firmware Restart” a 2nd time.

- The issue is can0 network disconnects when the restart causes a power cycle on your printer. The timing can be too fast and the can0 network doesn’t properly come back up. Another restart command is sometimes needed.
- | According to Klipper CANBUS docs, you might need to issue | sudo ip up in a SSH terminal to
restart the can0 network. I haven’t had to do this. But this might be useful during initial setup.

- | You can also use | sudo ip link set up can0 type can bitrate 500000 in a SSH terminal to start
can0 if it isn’t coming up with ifconfig. I have used this, but find that if the install instructions are followed then I don’t need it.
- See Klipper docs on CANBUS for official information https://www.klipper3d.org/CANBUS.html#usb-to-can-bus-bridge-mode
7. How to Use CanBoot to update boards, Tips

With CanBoot and Klipper now properly flashed to your Octopus / Pro board and EBB toolboard you now have two devices with unique CAN uuid on can0 network. But how to use CanBoot to upgrade Klipper firmware!?

When you run python3 flash_can.py | the python script should trigger the board to go into DFU
mode, to access CanBoot on the board and flash the Klipper update. I can’t cleanly get this to work with my Octopus Pro with F429 processor.
- Flashing with CAN uuid gives an error. Trying to use the original serial ID also gives an error.
- How I get it to work:
- Make Klipper firmware for Octopus board, cd to CanBoot/scripts
- I run: python3 flash_can.py -f ~/klipper/octopus_klipper.bin -u 463b35222d7b
- Note I am still moving and renaming firmware files. If you don’t want to do this then leave out: -f ~/klipper/octopus_klipper.bin and CanBoot defaults to using default location of Klipper firmware [ ~/klipper/out/klipper.bin ]
- CanBoot throws an error. If I try ifconfig, the can0 network is down
- Now if I try ls /dev/serial/by-id/* I get a serial ID:
- /dev/serial/by-id/usb-CanBoot_stm32f429xx_350026000B50314B33323220-if00
- Same as earlier…
- Now I run:
- python3 flash_can.py -f ~/klipper/octopus_klipper.bin -d /dev/serial/by-id/usb-CanBoot_stm32f429xx_350026000B50314B33323220-if00
- And CanBoot works and flashes Klipper update!
- I can now update the EBB with: python3 flash_can.py -f ~/klipper/ebb_klipper.bin -u 127081e7e3c6

Long story short;

1. Try to flash Octopus board with CAN uuid, it will fail and can0 network is down.
2. Now you can flash Octopus board with serial ID.
3. Lastly you can flash EBB board with CAN uuid.

CAN Bus Wiring on next page…

RJ11 / RJ12 CAN bus Wiring Info

To connect your EBB36/42 or other CAN enabled toolboard directly to the Octopus boards you need to use the RJ11 / RJ12 telephone port.

The easiest option is to use a 2-3 meter telephone cable and cut off one end. Crimp for Molex MiniFit or Molex MicroFit connector, depending on your CAN toolboard. The RJ11/12 connector goes to the Octopus board.

- This does not allow for twisted wire, which is recommended for CAN bus wiring.
- I have the 4 wire RJ11 telephone cable running directly to my EBB36, no twisted wire. No issues on my end but I will work to get twisted wire setup in the future.

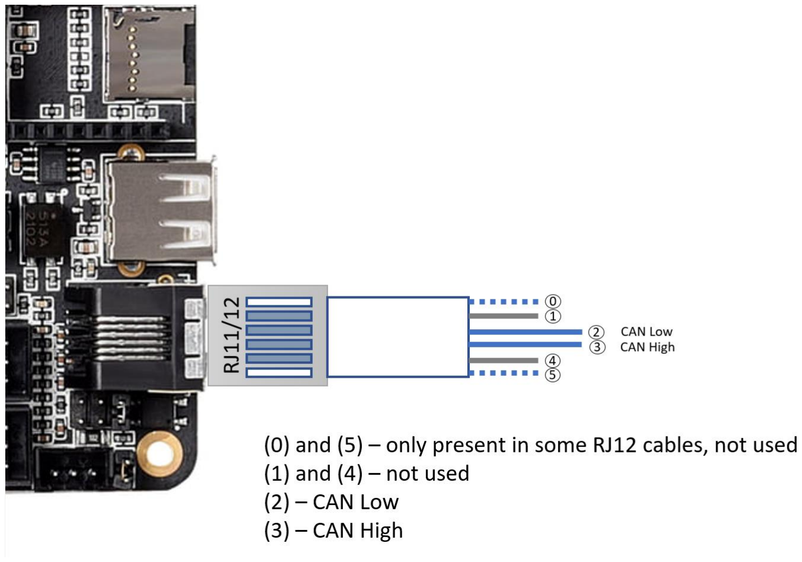
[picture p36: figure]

When you plug in the RJ11/12 cable to the Octopus board, the wiring (from top down) is as above. DO NOT RELY ON WIRE COLOURS. For example:

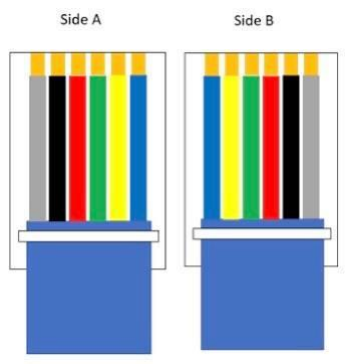
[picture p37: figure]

If plugging in a RJ12 cable with SIDE A your CAN Low wire is GREEN and CAN High wire is RED.

If plugging in a RJ12 cable with SIDE B your CAN Low wire is RED and CAN High wire is GREEN.

The colour of your wiring setup will be situational.

Take note of the wiring that you have plugged into the Octopus board. Wire 2 is your CAN Low connection. Note the colour of the wire and make sure it goes to CAN_L on the EBB end. Same thing for the CAN High on Wire 3. That colour wire goes to CAN_H on the EBB end.

You must also supply 12V or 24V directly to the EBB toolboard. Run 18awg directly from your power supply. Example EBB connections are below. Again, colours on the diagrams do not indicate wire colours.

EBB36

EBB42

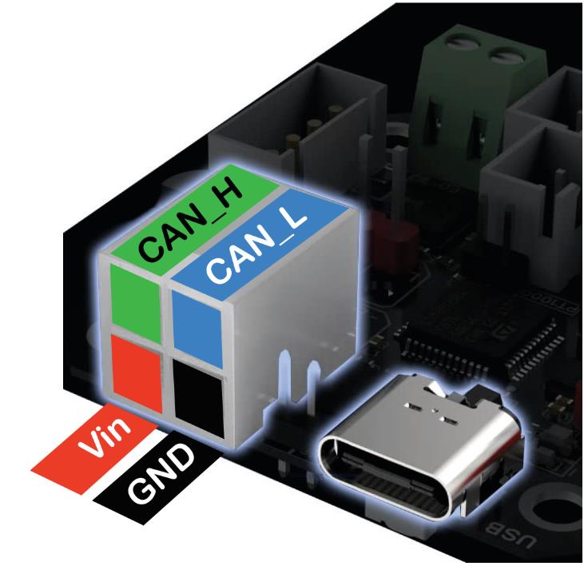
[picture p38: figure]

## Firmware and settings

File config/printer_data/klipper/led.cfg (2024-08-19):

#####################################################################
#   Introduction
#####################################################################

## This file is the configuration for the LEDs.
## 2 x Daylight on a stick
## 1 x Disco on a stick
## Stealthburner lights

#####################################################################
#   LED Control
#####################################################################

## Chamber Lighting - Connected to HE3 - 2 x Daylight on a stick
## Keep ground isolated from frame
[output_pin caselight]
pin: HE3
pwm: true
shutdown_value: 0
value: 0
cycle_time: 0.01

## PITB activity LED
[output_pin activity_led]
pin: PITB:LED_RUN

## RGB Chamber lighting - Connected to RGB Header
[neopixel case_led]
pin: NEOPXL_2
chain_count: 18
color_order: GRB
initial_RED: 0.0
initial_GREEN: 0.0
initial_BLUE: 0.0

## Stealthburner RGB
[neopixel SB2240_led]
pin: SB2240:RGBLED
chain_count: 3
color_order: GRBW
initial_RED: 0.0
initial_GREEN: 0.0
initial_BLUE: 0.0
initial_WHITE: 0.0

#####################################################################
#   Macros
#####################################################################

## Case lights - turn on and off
[menu __main __control __caselightonoff]
type: command
name: Caselight {'ON' if printer['output_pin caselight'].value > 0 else 'OFF'}
enable: {'output_pin caselight' in printer}
gcode:
    TOGGLE_CASELIGHT

## Control the brightness of the Caselight LEDs
[menu __main __control __caselightbrightness]
type: input
enable: {'output_pin caselight' in printer}
name: Brightness %: {'%3d' % (menu.input*100)}%
input: {printer["output_pin caselight"].value}
input_min: 0
input_max: 1
input_step: 0.1
gcode:
    SET_PIN PIN=caselight VALUE={menu.input}

[delayed_gcode caselight_off]
gcode:
    SET_PIN PIN=caselight VALUE=0

[gcode_macro TOGGLE_CASELIGHT]
gcode:
    {% if printer['output_pin caselight'].value > 0 %}
      SET_PIN PIN=caselight VALUE=0
    {% else %}
      SET_PIN PIN=caselight VALUE=1
    {% endif %}

[gcode_macro _rgb_vars]
# User settings for the StealthBurner status leds. You can change the status colors and led
# configurations for the logo and nozzle here.
variable_colors: {
        'case': {
            'busy': {'r': 0.4, 'g': 0.0, 'b': 0.0},
            'cleaning': {'r': 0.0, 'g': 0.02, 'b': 0.5},
            'calibrating_z': {'r': 0.8, 'g': 0., 'b': 0.35},
            'heating': {'r': 0.3, 'g': 0.18, 'b': 0.0},
            'homing': {'r': 0.0, 'g': 0.6, 'b': 0.2},
            'leveling': {'r': 0.5, 'g': 0.1, 'b': 0.4},
            'meshing': {'r': 0.2, 'g': 1.0, 'b': 0.0},
            'off': {'r': 0.0, 'g': 0.0, 'b': 0.0},
            'printing': {'r': 1.0, 'g': 0.0, 'b': 0.0},
            'standby': {'r': 0.11, 'g': 0.11, 'b': 0.11},        
        },
        'logo': { # Colors for logo states
            'busy': {'r': 0.4, 'g': 0.0, 'b': 0.0, 'w': 0.0},
            'cleaning': {'r': 0.0, 'g': 0.02, 'b': 0.5, 'w': 0.0},
            'calibrating_z': {'r': 0.8, 'g': 0., 'b': 0.35, 'w': 0.0},
            'heating': {'r': 0.3, 'g': 0.18, 'b': 0.0, 'w': 0.0},
            'homing': {'r': 0.0, 'g': 0.6, 'b': 0.2, 'w': 0.0},
            'leveling': {'r': 0.5, 'g': 0.1, 'b': 0.4, 'w': 0.0},
            'meshing': {'r': 0.2, 'g': 1.0, 'b': 0.0, 'w': 0.0},
            'off': {'r': 0.0, 'g': 0.0, 'b': 0.0, 'w': 0.0},
            'printing': {'r': 1.0, 'g': 0.0, 'b': 0.0, 'w': 0.0},
            'standby': {'r': 0.01, 'g': 0.01, 'b': 0.01, 'w': 0.1},
        },
        'nozzle': { # Colors for nozzle states
            'heating': {'r': 0.8, 'g': 0.35, 'b': 0.0, 'w':0.0},
            'off': {'r': 0.0, 'g': 0.0, 'b': 0.0, 'w': 0.0},
            'on': {'r': 0.8, 'g': 0.8, 'b': 0.8, 'w':1.0},
            'standby': {'r': 0.6, 'g': 0.0, 'b': 0.0, 'w':0.0},
        },
        'thermal': {
            'hot': {'r': 1.0, 'g': 0.0, 'b': 0.0, 'w': 0.0},
            'cold': {'r': 0.3, 'g': 0.0, 'b': 0.3, 'w': 0.0}
        }
    }
variable_case_led_name:         "case_led" 
# The name of the addressable LED chain that contains the logo LED(s)
variable_case_idx:              "1,2,3,4,5,6,7,8,9,10,11,12,13,14,15,16,17,18" 
# A comma-separated list of indexes LEDs in the logo
variable_logo_led_name:         "SB2240_led" 
# The name of the addressable LED chain that contains the logo LED(s)
variable_logo_idx:              "1" 
# A comma-separated list of indexes LEDs in the logo
variable_nozzle_led_name:       "SB2240_led"
# The name of the addressable LED chain that contains the nozzle LED(s). This will
# typically be the same LED chain as the logo.
variable_nozzle_idx:            "2,3"
# A comma-separated list of indexes of LEDs in the nozzle

variable_thermal_config: {
        'extruder': {
            'cool_temp': 40,
            'leds': 'logo',
        },
        'heater_bed': {
            'cool_temp': 40,
            'leds': 'nozzle',
        },
    }
# temperatures at which cooling will be considered complete

gcode:
    ; Do nothing

[gcode_macro _set_case_leds]
gcode:
    {% set red = params.RED|default(0)|float %}
    {% set green = params.GREEN|default(0)|float %}
    {% set blue = params.BLUE|default(0)|float %}
    {% set led = params.LED|string %}
    {% set idx = (params.IDX|string).split(',') %}
    {% set transmit_last = params.TRANSMIT|default(1) %}
    
    {% for led_index in idx %}
        {% set transmit=transmit_last if loop.last else 0 %}
        set_led led={led} green={green} red={red} blue={blue} index={led_index} transmit={transmit}
    {% endfor %}

[gcode_macro _set_sb_leds]
gcode:
    {% set red = params.RED|default(0)|float %}
    {% set green = params.GREEN|default(0)|float %}
    {% set blue = params.BLUE|default(0)|float %}
    {% set white = params.WHITE|default(0)|float %}
    {% set led = params.LED|string %}
    {% set idx = (params.IDX|string).split(',') %}
    {% set transmit_last = params.TRANSMIT|default(1) %}
    
    {% for led_index in idx %}
        {% set transmit=transmit_last if loop.last else 0 %}
        set_led led={led} red={red} green={green} blue={blue} white={white} index={led_index} transmit={transmit}
    {% endfor %}

[gcode_macro _set_case_leds_by_name]
gcode:
    {% set leds_name = params.LEDS %}
    {% set color_name = params.COLOR %}
    {% set color = printer["gcode_macro _rgb_vars"].colors[leds_name][color_name] %}
    {% set led = printer["gcode_macro _rgb_vars"][leds_name + "_led_name"] %}
    {% set idx = printer["gcode_macro _rgb_vars"][leds_name + "_idx"] %}
    {% set transmit = params.TRANSMIT|default(1) %}

    _set_case_leds led={led} red={color.r} green={color.g} blue={color.b} idx="{idx}" transmit={transmit}

[gcode_macro _set_sb_leds_by_name]
gcode:
    {% set leds_name = params.LEDS %}
    {% set color_name = params.COLOR %}
    {% set color = printer["gcode_macro _rgb_vars"].colors[leds_name][color_name] %}
    {% set led = printer["gcode_macro _rgb_vars"][leds_name + "_led_name"] %}
    {% set idx = printer["gcode_macro _rgb_vars"][leds_name + "_idx"] %}
    {% set transmit = params.TRANSMIT|default(1) %}

    _set_sb_leds led={led} red={color.r} green={color.g} blue={color.b} white={color.w} idx="{idx}" transmit={transmit}

[gcode_macro _set_caselight_leds]
gcode:
    {% set red = params.RED|default(0)|float %}
    {% set green = params.GREEN|default(0)|float %}
    {% set blue = params.BLUE|default(0)|float %}
    {% set led = printer["gcode_macro _rgb_vars"].case_led_name %}
    {% set idx = printer["gcode_macro _rgb_vars"].case_idx %}
    {% set transmit=params.TRANSMIT|default(1) %}

    _set_case_leds led={led} red={red} green={green} blue={blue} idx="{idx}" transmit={transmit}

[gcode_macro _set_logo_leds]
gcode:
    {% set red = params.RED|default(0)|float %}
    {% set green = params.GREEN|default(0)|float %}
    {% set blue = params.BLUE|default(0)|float %}
    {% set white = params.WHITE|default(0)|float %}
    {% set led = printer["gcode_macro _rgb_vars"].logo_led_name %}
    {% set idx = printer["gcode_macro _rgb_vars"].logo_idx %}
    {% set transmit=params.TRANSMIT|default(1) %}

    _set_sb_leds led={led} red={red} green={green} blue={blue} white={white} idx="{idx}" transmit={transmit}

[gcode_macro _set_nozzle_leds]
gcode:
    {% set red = params.RED|default(0)|float %}
    {% set green = params.GREEN|default(0)|float %}
    {% set blue = params.BLUE|default(0)|float %}
    {% set white = params.WHITE|default(0)|float %}
    {% set led = printer["gcode_macro _rgb_vars"].nozzle_led_name %}
    {% set idx = printer["gcode_macro _rgb_vars"].nozzle_idx %}
    {% set transmit=params.TRANSMIT|default(1) %}

    _set_sb_leds led={led} red={red} green={green} blue={blue} white={white} idx="{idx}" transmit={transmit}

[gcode_macro set_case_leds_off]
gcode:
    {% set transmit=params.TRANSMIT|default(1) %}
    _set_caselight_leds red=0 blue=0 green=0 transmit={transmit}
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

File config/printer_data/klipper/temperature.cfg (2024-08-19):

#####################################################################
#   Introduction
#####################################################################

## This file is the configuration for non-controlling thermistors.

#####################################################################
#   Temperaure
#####################################################################

# Raspberry Pi Temperature
# [temperature_sensor raspberry_pi]
# sensor_type: temperature_host
# min_temp: 0
# max_temp: 120

# MCU Temperature
[temperature_sensor Octopus-Pro]
sensor_type: temperature_mcu
min_temp: 0
max_temp: 120

# PITB Temperature
[temperature_sensor PITB]
sensor_type: temperature_mcu
sensor_mcu: PITB
min_temp: 0
max_temp: 120

# SB2240 Temperature
[temperature_sensor SB2240]
sensor_type: temperature_mcu
sensor_mcu: SB2240
min_temp: 0
max_temp: 120

# SB2240 Toolhead Temperature
[temperature_sensor TOOLHEAD]
sensor_type: Generic 3950
sensor_pin: SB2240:TH0
min_temp: 0
max_temp: 120 

# Sensor on gantry connected to PITB
[temperature_sensor Gantry]
sensor_type: Generic 3950
sensor_pin: PITB:THERM0
min_temp: 0
max_temp: 85
gcode_id: C

##  Exhaust fan - FAN3
[temperature_sensor external_case]
sensor_pin: T1
sensor_type: Generic 3950

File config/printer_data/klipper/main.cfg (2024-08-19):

#####################################################################
#   Intro
#####################################################################

# This file is linked to from the local printer.cfg.
# This can be edited and the then remotely updated.
# The file is modular, so editting sections is easier.

#####################################################################
#   MCUs
#####################################################################

# Octopus Pro Control Board and Canbridge - Main MCU
# Controls Z, bed, power, leds and enclosure fans
[include /home/adam/voron-2-300/config/printer_data/klipper/octopus_pro.cfg]
# PITB Canbus board. The is controls A/B movement and end stops.
# Also has a thermistor to measure chamber temperatures
[include /home/adam/voron-2-300/config/printer_data/klipper/pitb.cfg]
# Fly-SB2040 Canbus board. This controls the stealthburn toolhead.
# [include /home/adam/voron-2-300/config/printer_data/klipper/fly-sb2040.cfg]
# BTT EBB-SB2240 board
[include /home/adam/voron-2-300/config/printer_data/klipper/ebb-sb2240.cfg]

#####################################################################
#   Fluidd
#####################################################################

[include /home/adam/voron-2-300/config/printer_data/fluidd/fluidd.cfg]

#####################################################################
#   Printer
#####################################################################

[printer]
kinematics: corexy
max_velocity: 300  
max_accel: 3000             #Max 4000 -> Input shaper -> 8200 on X, 5200 on Y
max_z_velocity: 15          #Max 15 for 12V TMC Drivers, can increase for 24V
max_z_accel: 500
square_corner_velocity: 5.0

#####################################################################
#   Power Settings
#####################################################################

# All the power commands are in this module
[include /home/adam/voron-2-300/config/printer_data/klipper/power.cfg]

#####################################################################
#   Z Stepper Settings
#####################################################################

# Z configuration
[include /home/adam/voron-2-300/config/printer_data/klipper/z.cfg]

#####################################################################
#   X/Y Stepper Settings
#####################################################################

# X and Y configuration and input shaper
[include /home/adam/voron-2-300/config/printer_data/klipper/x_and_y.cfg]
[include /home/adam/voron-2-300/config/printer_data/klipper/input_shaper.cfg]

#####################################################################
#   Extruder
#####################################################################

# Extruder config
[include /home/adam/voron-2-300/config/printer_data/klipper/extruder.cfg]
# Filament Sensor
[include /home/adam/voron-2-300/config/printer_data/klipper/filament_sensor.cfg]

#####################################################################
#   Probe
#####################################################################

[include /home/adam/voron-2-300/config/printer_data/klipper/probe.cfg]

#####################################################################
#   Bed Heater
#####################################################################

# Bed Config
[include /home/adam/voron-2-300/config/printer_data/klipper/bed.cfg]

#####################################################################
#   Temperature
#####################################################################

[include /home/adam/voron-2-300/config/printer_data/klipper/temperature.cfg]

#####################################################################
#   Fan Control
#####################################################################

[include /home/adam/voron-2-300/config/printer_data/klipper/fan.cfg]

#####################################################################
#   LED Control
#####################################################################

[include /home/adam/voron-2-300/config/printer_data/klipper/led.cfg]

#####################################################################
#   Displays
#####################################################################

[include /home/adam/voron-2-300/config/printer_data/klipper/display.cfg]

#####################################################################
#   Macros
#####################################################################

[include /home/adam/voron-2-300/config/printer_data/klipper/print_setup.cfg]
[include /home/adam/voron-2-300/config/printer_data/klipper/TEST_SPEED.cfg]

#####################################################################
#   Arc Support
#####################################################################

[gcode_arcs]
#resolution: 1.0

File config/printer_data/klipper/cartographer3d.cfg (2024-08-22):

[cartographer]
# serial:
#   Path to the serial port for the Cartographer device. Typically has the form
#   /dev/serial/by-id/usb-cartographer_cartographer_...
#   
#   If you are using the CAN Bus version, replace serial: with canbus_uuid: and add the UUID.
#   Example: canbus_uuid: 1283as878a9sd
canbus_uuid: 
#
speed: 40.
#   Z probing dive speed.
lift_speed: 5.0
#   Z probing lift speed.
backlash_comp: 0.5
#   Backlash compensation distance for removing Z backlash before measuring
#   the sensor response.
# 
#   Offsets are measured from the centre of your coil, to the tip of your nozzle 
#   on a level axis. It is vital that this is accurate. 
#
x_offset: 0.0
#   X offset of cartographer from the nozzle.
y_offset: 21.1
#   Y offset of cartographer from the nozzle.
trigger_distance: 2.0
#   cartographer trigger distance for homing.
trigger_dive_threshold: 1.5
#   Threshold for range vs dive mode probing. Beyond `trigger_distance +
#   trigger_dive_threshold` a dive will be used.
trigger_hysteresis: 0.006
#   Hysteresis on trigger threshold for untriggering, as a percentage of the
#   trigger threshold.
cal_nozzle_z: 0.1
#   Expected nozzle offset after completing manual Z offset calibration.
cal_floor: 0.1
#   Minimum z bound on sensor response measurement.
cal_ceil: 5.0
#   Maximum z bound on sensor response measurement.
cal_speed: 1.0
#   Speed while measuring response curve.
cal_move_speed: 10.0
#   Speed while moving to position for response curve measurement.
default_model_name: default
#   Name of default cartographer model to load.
mesh_main_direction: x
#   Primary travel direction during mesh measurement.
#mesh_overscan: -1
#   Distance to use for direction changes at mesh line ends. Omit this setting
#   and a default will be calculated from line spacing and available travel.
mesh_cluster_size: 1
#   Radius of mesh grid point clusters.
mesh_runs: 2
#   Number of passes to make during mesh scan.

[adxl345 probe]
cs_pin: cartographer:PA3
spi_bus: spi1

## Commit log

2023-07-28 changed canbus speed
2023-07-28 Update octopus_pro_f429.config
    change rate to 1MB for canbus
2023-08-16 Updated the documentation
    [BTT_Sensor_Mount_A.stl, BTT_Sensor_Mount_B.stl, BTT_UPS_24V_DIN.stl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]
2023-08-17 Added config and updated klipper binaries
    [fluidd.cfg, fly-sb2040.cfg, printer-20230810_232204.cfg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]
2023-08-17 Fixed incorrect directory with canbridge
    [fluidd.cfg, fly-sb2040.cfg, nevermore.cfg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]
2023-08-17 Updated config files to be modular
    [bed.cfg, display.cfg, extruder.cfg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]
2023-08-17 Bug fixes
    [fluidd.cfg, fly-sb2040.cfg, nevermore.cfg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]
2023-08-17 Fixed include references
    [fluidd.cfg, fly-sb2040.cfg, main.cfg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]
2023-08-17 fixed fluidd bug
    [fluidd.cfg, main.cfg, moonraker.cfg]
2023-08-17 Fixed klipper install cfg
    [printer.cfg]
2023-08-17 fixed typo in led cfg file
    [led.cfg]
2023-08-17 fixed missing macro on led.cfg
    [led.cfg]
2023-08-17 fixed typo
    [led.cfg]
2023-08-17 fixed typo in led macro
    [led.cfg]
2023-08-17 removed white from case led
    [led.cfg]
2023-08-17 fixed case led not initiating
    [led.cfg]
2023-08-17 Fix for case led
    [led.cfg]
2023-08-18 macro tweaks
    [power.cfg, print_setup.cfg]
2023-08-18 Attempt to fix LED during print.
    [TEST_SPEED.cfg, main.cfg, print_setup.cfg]
2023-08-18 Attempt to fix speed test
    [TEST_SPEED.cfg]
2023-08-18 Added pressure advance
    [extruder.cfg, print_setup.cfg]
2023-08-18 Updated acceleration
    [main.cfg]
2023-08-18 set chamber temperature before bed starts to heat
    [print_setup.cfg]
2023-08-19 Reduced acceleration temporarily
    [main.cfg]
2023-08-19 Slowed down print temporarily
    [main.cfg]
2023-08-20 Added new external temperature sensor
    [LED Spacer.stl, Voron_Design_Cube_v7.stl, rear_center_skirt_300_custom.stl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]
2023-08-20 fixed sensor pin
    [power.cfg, temperature.cfg]
2023-08-21 Added exclude object
    [[a]_handle_middle_part.stl, main.cfg]
2023-08-26 Change external temp for diagnostics
    [temperature.cfg]
2023-08-27 Added filament sensor
    [filament_sensor.cfg, main.cfg, print_setup.cfg]
2023-08-28 Moved x endstop to toolhead
    [x_and_y.cfg]
2023-08-28 test for x endstop
    [x_and_y.cfg]
2023-08-30 UPdate to fix exclude object
    [2020 Rail Endstop.stl, Short_Arm.stl, Z Belt Pi Cam B Logo.stl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]
2023-09-06 increased max temp on external
    [temperature.cfg]
2023-09-06 remove temperature limit
    [temperature.cfg]
2023-09-12 Updated klipper binaries
2023-12-12 config updat
    [print_setup.cfg]
2023-12-13 Changed fan to monitor raspberry pi
    [fan.cfg, temperature.cfg]
2023-12-13 fan config fix
    [fan.cfg]
2023-12-13 removed fan speed
    [fan.cfg]
2023-12-13 reduced max power to rpi fan
    [fan.cfg]
2023-12-13 increase max power to rpi fan
    [fan.cfg]
2023-12-13 test for x and y
    [x_and_y.cfg]
2023-12-13 revert test
    [x_and_y.cfg]
2023-12-14 updated x and y config
    [TEST_SPEED.cfg, led.cfg, x_and_y.cfg]
2023-12-14 Tidy up x and y config
    [x_and_y.cfg]
2023-12-29 Changed to magnestic panels
    [Corner-Clip-6mm.stl, Corner-Clip-7mm.stl, Install-Jig.stl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]
2024-02-13 Added arc support
    [main.cfg]
2024-02-13 Updated print start script
    [1_coal_with_mesh.stl, 1_hepa.stl, 1_lid.stl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]
2024-05-05 Fixed updater issue with canbus bootloader
2024-08-19 Changed to sb2240 and g2e
    [ebb-sb2240.cfg, extruder.cfg, fan.cfg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]
2024-08-19 Fix for alias in ebb
    [ebb-sb2240.cfg]
2024-08-19 Fixed fan issue
    [ebb-sb2240.cfg]
2024-08-19 fixed toolhead temp
    [temperature.cfg]
2024-08-19 fixed sensor pin on toolhead
    [temperature.cfg]
2024-08-19 attempt to fix spi error
    [ebb-sb2240.cfg, input_shaper.cfg]
2024-08-19 SPI alias fix
    [ebb-sb2240.cfg]
2024-08-19 miso fix
    [ebb-sb2240.cfg, input_shaper.cfg]
2024-08-22 started adding cartographer
    [cartographer3d.cfg, ebb-sb2240.cfg, extruder.cfg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]
